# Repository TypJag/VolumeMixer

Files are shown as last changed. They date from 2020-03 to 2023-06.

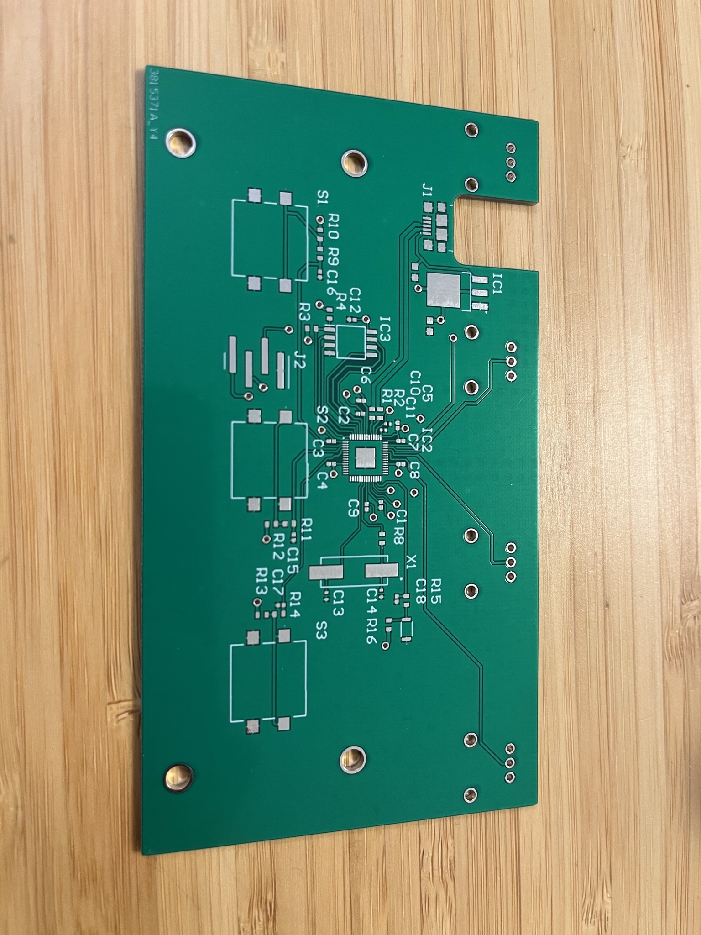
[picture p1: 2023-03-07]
Dokumentation/Bilder/IMG_0470.JPEG

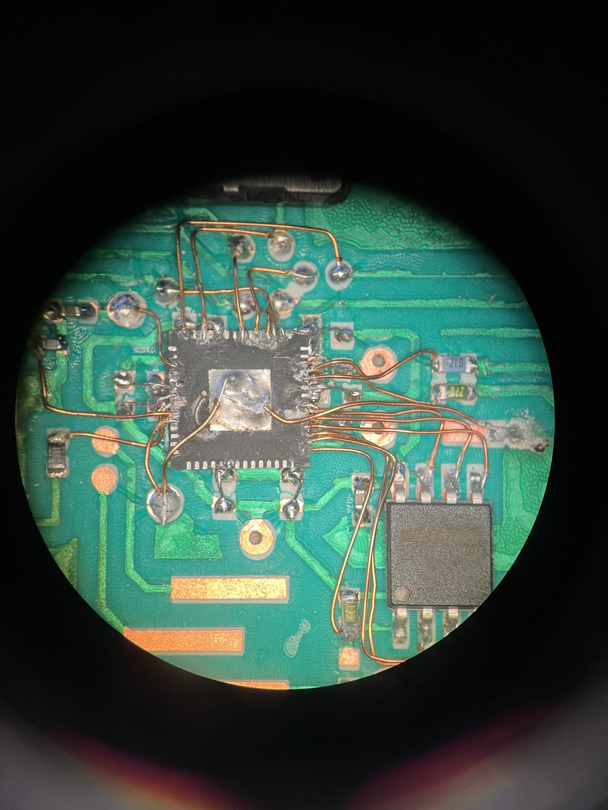
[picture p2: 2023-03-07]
Dokumentation/Bilder/IMG_0460.JPEG

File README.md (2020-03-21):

# VolumeMixer
A python script and arduino code for a hardware volume mixer for programs running on a Windows system

Link to a gallery of the project: https://www.sweclockers.com/galleri/15041-volymmixer

The hardware used is a simple arduino nano clone. 

Some modifications of the python script might be required for it to work with another arduino. In the findarduinoNano function there is a int called pid which is used to identifi COM-port the arduino is connected to. More intructions is in the comments in the script.

The shortcut needs to be uppdated with the correct path to the python script and the python install directory.

Some packages are needed to run the python script. More info in the script.

The arduino code requires bounce2.h. https://github.com/thomasfredericks/Bounce2

This project uses nircmd.exe by NirSoft https://www.nirsoft.net/utils/nircmd.html

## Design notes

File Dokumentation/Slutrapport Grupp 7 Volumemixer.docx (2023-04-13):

# Projekt VolumeMixer

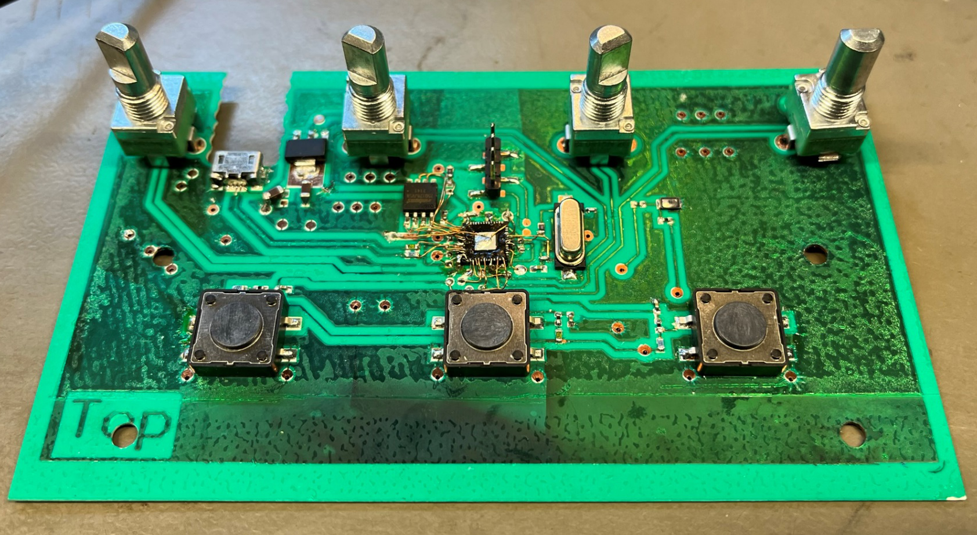
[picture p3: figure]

# Slutrapport för grupp 7

Vårtermin 2023

Axel Andersson Axean603

Linköpings universitet

# Sammanfattning

I detta projekt har ett kretskort för utvecklats. Kortets funktion är att agera ett fysiskt gränssnitt för att kontrollera individuella applikationers ljudvolym som körs på en vanlig dator. Kortet ger också möjlighet att styra uppspelningen av media på datorn genom att ha tre knappar som kontrollerar paus/play, nästa låt och föregående låt.

För att utföra dessa funktioner så används en Raspberry RP2040 mikrokontroller som kommunicerar användarens kommandon till en dator via USB. Närmare bestämt kommunicerar mikrokontrollern med ett Python skript som utför användarens kommandon.

För att kunna implementera RP2040 mikrokontrollern var ett ovanligare monteringssätt tvungen att användas för att arbeta runt de begränsningarna som finns i när mönsterkort görs i Linköpings Universitets mönsterkortslaboratorium. För att komma runt begränsningarna så ”dead bug” monterades mikrokontrollern, d.v.s. att kretsen lades på rygg och sedan drogs korta patchtrådar ut från kompentens paddar ut till paddar på mönsterkortet.

Efter kort felsökning av kortet efter montage startade mikrokontrollern och kortet fungerar som förväntat.

# Innehåll

# Förkortningar

Förkortning | Betydelse
Liu | Linköpings Universitet
MCU | Mikrokontroller
GPIO | Generel Purpose Input Output
I/O | Input Output
LDO | Low-dropout regulator
SRAM | Static Random Access Memory
ADC | Analog Digital Konverterare
SPI | Serial Peripheral Interface

# 1 Introduktion

En stor del av jobbet som elektronikingenjör är att konstruera kretsar. Dessa kretsar av olika slag måste därefter realiseras på ett eller annat sätt.

Det som har visat sig vara det dominerande alternativet att realisera kretsar idag är mönsterkort. En konstruktionsmetod som både har stora fördelar i produktions sammanhang samt tillåter den moderna elektronikingenjören konstruera mycket små kretsar av olika former och slag. Mönsterkort har också fördelen att man kan konstruera sina kretsar med mycket fin kontroll över geometrin av ledarna vilket kan användas till stor fördel då frekvenserna i signalerna stiger.

Som då blivande elektronikingenjörer är ett naturligt steg i utbildningen att vi ska bekanta oss med mönsterkortens konstruktion och produktion, vilket är målet och syftet med kursen ”Metoder och processer vid elektronikproduktion” (TNE087) som det här projektet är en del av.

Projektet har innefattat att konstruera en elektrisk konstruktion av valfri modell och sedan realisera den på ett mönsterkort.

Målet med det här projektet har mer specifikt varit att implementera Raspberry Pi Foundations mikrokontroller RP2040. Mikrokontrollerns mening är då att agera som fysiskt användargränssnitt för volymmixern som finns inbyggt i Windowsdatorer som ställer ljudvolymen för olika program som körs på datorn.

Kortet skulle också vara anpassat för att kunna tillverkas i Linköpings Universitets (Liu) mönsterkortslaboratorium. Mönsterkorten tillverkas där med hjälp av en etsande metod där en fotofilm används för att exponera valda delar utav en fotoresist.

Rekommenderade begränsningarna i mönsterkortslaboratoriumet är kortfattat:

- Två lager
- 160x160 mm
- Minsta ledarbredd 0,4 mm
- Minsta clearance ledare 0,5 mm
- Minsta borrdiameter 0,4 mm

# 2 Kortets kretsar och deras implementation

Nedan finns information gällande de kretsar som användes på kortet och hur de skall implementeras.

## Raspberry Pi Foundations RP2040

Kortfattat är RP2040 en lågkostnads, högpresterande mikrokontroller.

Nyckelfunktioner är som följande:

- Dubbla Cortex M0+ kärnor, klockade upp till 133 MHz
- 264 kB av integrerat SRAM
- 30 multifunktionella GPIO (General Purpose Input Output)
- Dedikerad hårdvara för vanliga kringutrustningar
- 4-kanalers ADC (Analog digital konverterare)
- USB 1.1 Host/Device

[1]

Se figur 1 nedan för en översikt av RP2040 interna uppbyggnad.

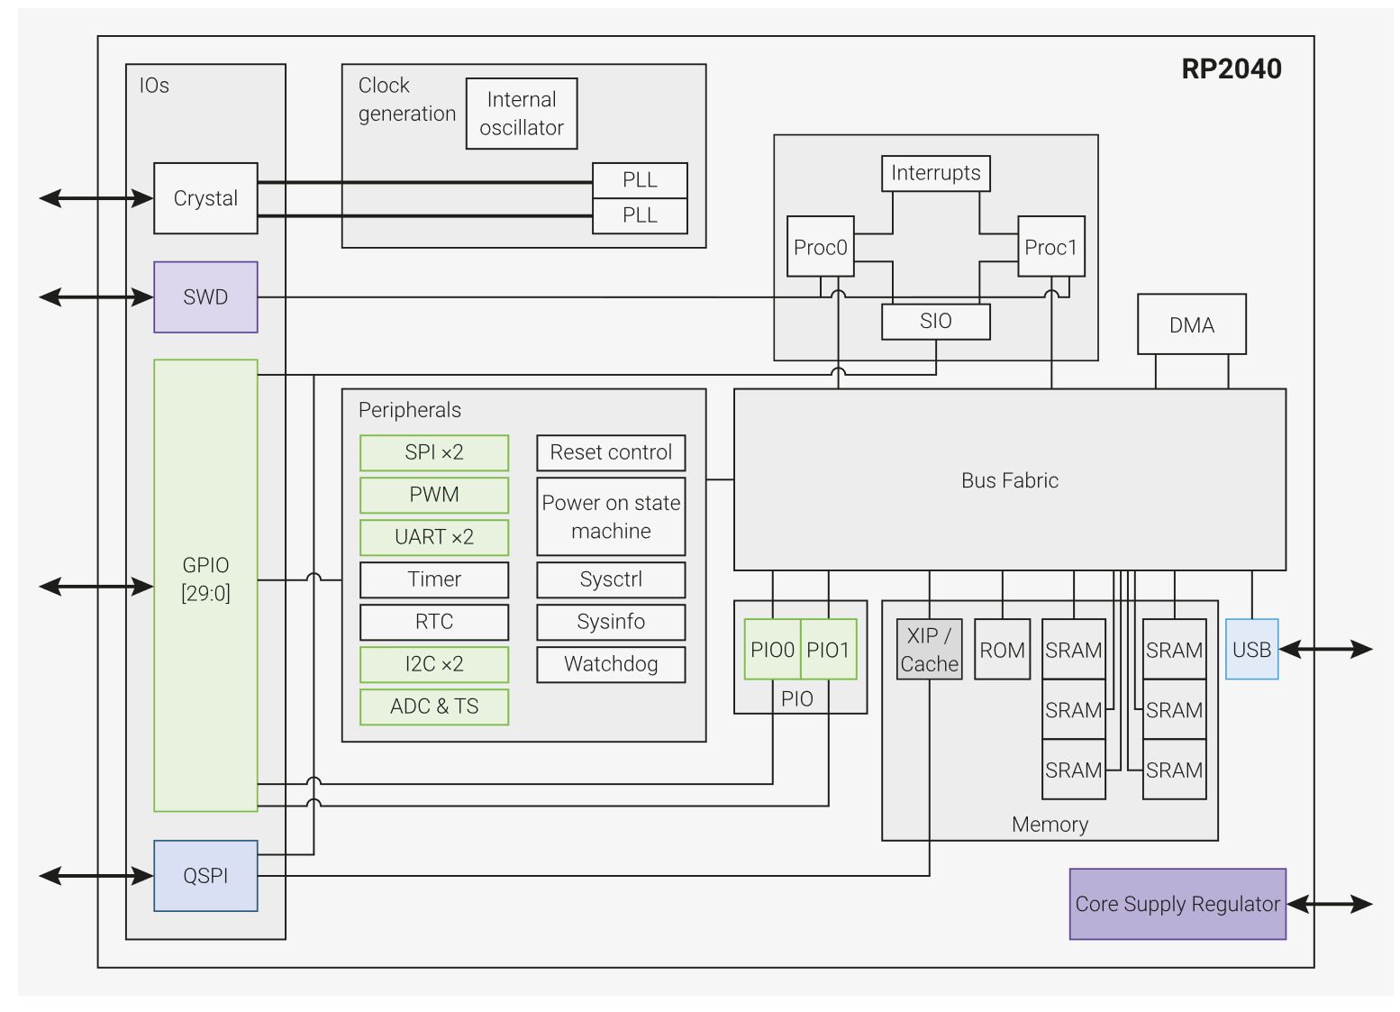
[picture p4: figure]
En bild som visar diagram, schematisk Automatiskt genererad beskrivning

Figur 1 Översikt över RP2040's interna uppbyggnad. Figuren är tagen från kretsens datablad [1].

För att framgångsrikt implementera RP2040 kretsen krävs följande tre saker [2]:

- Spänningsmatning
- SPI-minne
- Kristalloscillator

Mer ingående beskrivningar av vad som krävs kan läsas nedan.

### Spänningsmatning

RP2040 kräver två spänningar 3,3 V (för I/O) och 1,1 V (för kretsens digitala kärna) [2]. Praktiskt nog finns en inbyggd LDO (Low-dropout regulator) som kan användas för att generera 1V1 till kretsen.[2]

### Inkommande matning

Kortet kommer alltid vara inkopplad till en dator och kommer därför alltid att matas med 5 V. Den inkommande 5 V kan sedan användas för att generera 3,3 V som kan användas för att driva RP2040 kretsen.

För att generera 3,3 V i den här konstruktionen användes en LDO. Närmare bestämt användes Onsemi’s NCP1117ST33T3G dels för att den rekommenderas i Raspberry Pi foundation’s ”hardware design with RP2040” [2] och för att den råkade finns i Litheels lager. LDOn skall enligt dess datablad ha en kondensator på 1 0µF kopplat till inkommande spänning och en kopplad till utgående spänning [3].

### Avkopplingskondensatorer

Till RP2040 rekommenderas det att det finns avkopplingskondensatorer i närheten av paddarna för inkommande spänningsmatning till kretsen [2]. Generellt är rekommendationen 100 nF vid varje padd samt 1 µF i närheten av padden till LDOn som genererar 1,1 V [2]. 1,1 V rekommenderas också finns i närheten av utgången från LDOn. Dessa kondensatorer har två grundläggande funktioner, att filtrera ut brus som finns på spänningsmatningen och vara en källa till energi som RP2040 kretsen kan använda när den tillfälligt använder mycket energi till exempel vid omslag på en utgång [2].

### SPI-minne

För att kunna spara programkod som mikrokontrollern kan köra så krävs ett externt minne. I det här fallet användes ett W25Q128JVS vilket är ett quad SPI (Serial Peripheral Interface) flash minne på 128 Mbit. Detta minne valdes i och med att det användes i Raspberry Pi Foundations ”hardware design with RP2040” implementation [2].

### Kristalloscillator

Tekniskt sätt behövs inte en extern oscillator för RP2040 skall fungera utan den har en inbyggd oscillator men i och med att den inte är speciellt stabil rekommenderar Raspberry Pi Foundation att en extern klockkälla bör användas. I det här fallet användes en ABLS-12.000MHZ-B4-T vilket är en 12 MHz kristalloscillator. Den implementerades i enlighet med Raspberry Pi Foundations ”hardware design with RP2040” rekommendationer [2].

## Partikulära detaljer relaterat med det här kortets funktioner

### USB

RP2040 har möjlighet att kommunicera över USB i fullspeed(12Mbps) och lowspeed(1.5Mbps) [1] som antingen host eller device. För det här projektet så utnyttjades det genom att RP2040n konfigurerades att agera som device och kommunicera med ett Python skript på värddatorn med hjälp av en virtuell serieport som kommuniceras över USB. Ytterligare så programmeras kretsen enklast över USB så en fungerande USB implementation var ett krav.

För att USB skall fungera som förväntat så finns vissa krav kortet. Närmare bestämt bör ledarna för USB data paret dels vara terminerade med ett varsitt seriekopplat 27.4 Ω motstånd och att parets ledare skall ha en differentiell impedans på 90 Ω [2].

### I/O som används

Totalt kommer sju I/O pinnar att användas. De fyra pinnarna som är kopplad till de fyra kanalerna på den interna ADCn i RP2040n kommer att kopplas till varsin potentiometer och kommer att användas för att kontrollera volymen för fyra olika applikationer som kör på värddatorn. Tre I/O pinnar kommer vara kopplade till tre tryckknappar.

# 3 Projektets genomförande

## Konstruktion av schema

Schemat konstruerades i enlighet med de krav som detaljeras under rubriken 3 ”Detaljer kring kortets kretsar och deras implementation”. Majoriteten av schemasymbolerna och PCB footprintsen importerades med hjälp av Altium Library Loader för att spara tid. En del av symbolerna så som symbolen för RP2040 modifierades dock för att öka läsbarheten i schemat. Även en del av PCB footprinten modifierades för att korrigera fel från den troligen automatiserade processen som Altium Library Loader använder för att ska symbolerna och footprinten hade fått med. Komplett schema kan ses i bilaga 3.

## Konstruktion av layout

Två varianter konstruerades, en variant anpassad att tillverkas av ett vanligt produktionshus i det här fallet JLCpcb och en variant anpassad för att tillverkas i Lius mönsterkortslaboratorium. Storleken på kortet samt var potentiometrarna, monteringshål och tryckknapparna är placerades bestämdes utifrån den redan tillverkade mekaniken. Komplett layout kan ses i bilaga 2.

### Variant anpassad för JLCpcb

För JLCpcb konstruerades en variant på kortet som var anpassad för deras enklaste två lagers kort. Exakta begränsningar kan läsas på JLCpcbs hemsida [4].

### Variant anpassad för Lius mönsterkortslaboratorium

Att anpassa kortet för att kunna tillverkas på Lius mönsterkortslaboratorium var en större utmaning ty begränsningarna var större och marginalerna måste därför ökas för att lyckas producera ett fungerande mönsterkort.

Den största svårigheten med att anpassa den här konstruktionen att vara producerabar i Lius mönsterkortslaboratorium var hur footprinten för RP2040 mikrokontrolern skulle utformas. RP2040 kretsen är i en så kallad QFN-56 kapsling som är 7x7 mm stor med en pitch på 0.4 mm mellan benen. Att lyckas tillverka det footprintet framgångsrikt i Lius mönsterkortslaboratorium hade varit en stor utmaning. Istället togs beslutet att kretsen skulle monteras i ”dead bug” stil d.v.s. att kretsen läggs på rygg och små patch trådar dras från komponentens ben till paddar på kortet. På det sättet kan större geometrier göras på kortet och vilket gör att kortet är enklare att producera.

För att framgångsrikt kunna ”dead bug” montera kretsen gjordes även en del anpassningar på omkringliggande kretsar och komponenter. Den största anpassningen var hur avkopplingskondensatorerna placerades och monterades. Istället för att bara montera dem direkt på kortet ställdes de på högkant längs med kanten på mikrokontrollern och då kondensatorer i storleken 0402 användes var kondensatorerna lika långa som mikrokontrollern var tjock. Vilket gjorde inkopplingen av kondensatorerna väldigt enkel. Ytterligare modifierades vissa av footprinten för kondensatorerna för att kunna montera flera kondensatorer mot samma padd för att passa in med hur spänningsmatningspinnararna var placerade på mikrokontrollern.

## Test av kort efter tillverkning

### Omonterat kort

Följande steg skall tas vid verifikation av omonterat kort.

- Alla ledare skall testas med en ohmmeter för att se att ledaren är kontinuerlig som förväntad.
- Alla ledare skall testas med en ohmmeter mot lämpliga närliggande ledare för att se att det inte finns några oväntade kortslutningar
- En visuell inspektion skall genomföras för att verifiera att mönsterkortet ser välskapt ut och inga uppenbara fel kan ses.

### Monterat kort innan uppstart

Följande steg skall tas vid verifikation av monterat kort innan uppstart.

- Alla ledare skall testas med en ohmmeter för att se att ledaren är kontinuerlig som förväntad och att lödningarna har utförts som de ska.
- Alla ledare skall testas med en ohmmeter mot lämpliga närliggande ledare för att se att det inte finns några oväntade kortslutningar
- En visuell inspektion skall genomföras för att verifiera att kretskortet ser välskapt ut och inga uppenbara fel kan ses.

### Monterat kort efter uppstart

Följande steg skall tas vid verifikation av monterat kort innan uppstart.

- Följande spänningsmatningarna skall mätas: 5 V 3,3 V samt 1,1 V.
- Kristalloscillatorn skall mätas för att verifiera att klockan har startat och har förväntad frekvens
- Kortet skall kopplas in till dator och programmeras
- Kortets funktioner skall verifieras genom att köra det förväntade programmet som kommunicerar potentiometrarnas läge samt tryckknapparnas status till värddatorn.
- Kortet skall monteras i mekaniken för att se att det passar

## Felsökning av kortet

### Vid första start

Strömbegränsningen nådes. Kortslutning mellan 3,3 V och jord. Försökte med värmekamera identifiera var. Var dock svårt att se exakt var men värmekameran gav ett område. Kapade därefter ledare för att undersöka närmare. Hittade en lödbrygga vid en av avkopplingskondensatorerna.

### Vid andra start

Strömbegränsningen nådes. Kopplade förbi LDOn och matar med 3,3 V direkt. Kortet drar mer rimligt ström. Ca 7 mA. Inget händer och 1,1 V generas inte som den ska. Testade experimentera med hur run signalen görs. Inget resultat. Bekräftar därefter att alla signaler är inkopplade som förväntat. Inget resultat.

Gör därefter en gissning att mikrokontrollern har dött vid experiment. Byter ut mikrokontrollern. Monterar den med absolut minsta möjliga inkopplingar. Endast matningar, klocka samt run och testenable inkopplat.

### Verifikation av inkoppling efter montage

Mäter då resistansen mellan 3,3 V och GND 0.8 Ω. Kopplar lös GND kopplingen till kretsen och mäter mellan GND benet på kretsen och 3,3 V på kretsen. Fortfarande 0.8 Ω.

Mäter på en ny omonterad krets. Fortfarande 0.8 Ω. Mäter där efter mellan benen för spänningsmatningen för 3,3 V. De bör vara ihopkopplade internt. Konstaterar då att kretsen är monterad 90 grader fel. Vid montage vändes kretsen kring fel axel.

### Justerar monteringen av kretsen

Verifierar att kretsen var rätt vriden och att inget är kortslutet. Kortet startar som förväntat. 1,1 V genereras som förväntat och klockan går. Kretsen svarar också som förväntat när den kopplas till en dator. Programmering tar dock inte.

### Verifikation av inkoppling av SPI-minne

Konstaterar att SD3 och SD0 har bytt plats vid montering. Efter korrigering kan kortet programmeras och tryckknapparna samt potentiometrarna ger utslag som förväntat.

# 4 Resultat

## Monterade kort tillverkade av JLCpcb

Se figur 2 nedan för resultat

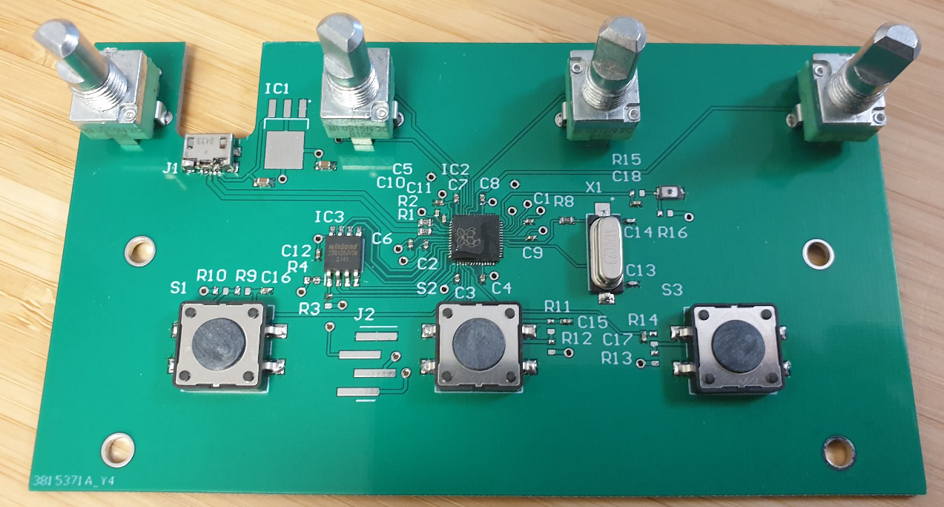
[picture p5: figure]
En bild som visar elektronik, krets Automatiskt genererad beskrivning

Figur 2 Monterat kretskort med mönsterkort tillverkat av JLCpcb

## Monterade kort tillverkade i Lius mönsterkortslaboratorium

Se figur 3 och 4 nedan för resultat

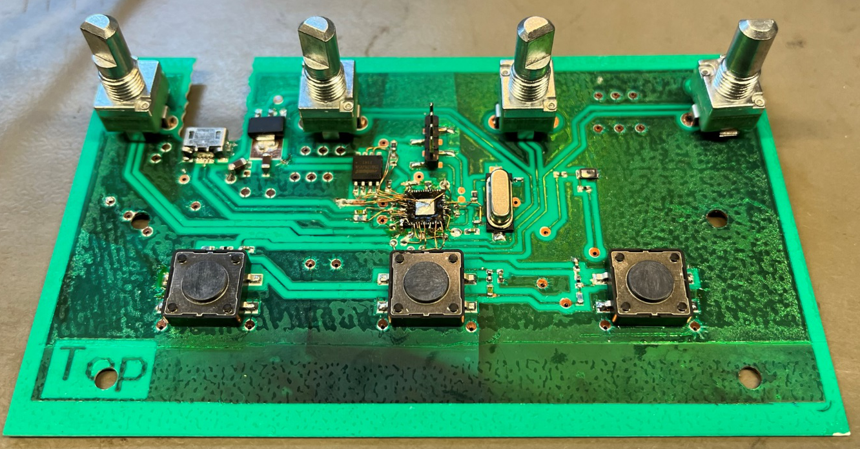
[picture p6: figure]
En bild som visar text, elektronik, krets Automatiskt genererad beskrivning

Figur 3 Monterat kretskort med mönsterkort tillverkat i Lius mönsterkortslaberatorium

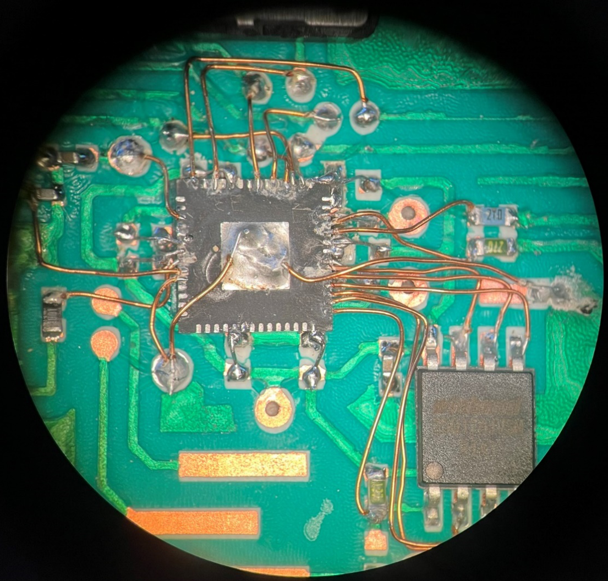
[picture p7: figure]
En bild som visar text Automatiskt genererad beskrivning

Figur 4 "Dead bug" monterad MCU

# 5 Diskussion och slutsatser

## Varför kortet inte riktigt blev som underlaget

Som kan ses på några av ledarna i figur 3 så finns en del förvrängningar i det slutgiltiga resultatet. En del av ledarna har blivit betydligt tunnare än förväntat.

Den största faktorn för varför de blev så pass förvrängda i visa områden är troligen att fotofilmen blev förvrängd när den skrevs ut. Det var stora problem med att få skrivaren att fungera när fotofilmen skulle göras. Hade både problem med att få den att skriva ut överhuvudtaget och när den väl skrev ut var allt förskjutet i y-led. Nu visade det sig att dessa förvrängningar inte var ett problem och kortet fungerade som förväntat.

## Potentiella förbättringar

Nedan är några idéer på förbättringar som kunde ha gjorts på konstruktionen samt vid montage.

- Ett tjockare laminat kunde ha använt för att få ett stabilare kort. Nu sviktar kortet något när knapparna trycks ned. Vid tillverkning fanns dock inget Rogers laminat i tjockare tjocklekar tillgängligt.
- Hållen för montering till chassit kunde ha inkluderats i underlaget och varit i korrekt storlek. Lades in manuellt i drill-filen, dock tyvärr som 3mm hål istället för 4mm som de borde ha varit.
- Olackade koppartrådar kunde ha använts med teflon slangar som isolation istället för lackade koppartrådar. Skulle potentiellt ha sparat en del tid vid montage. Har sätt det användas på projekt på internet och skulle vara intressant att testa och jämföra med nuvarande metod.

# 6 Slutsats

Det går att implementera en RP2040 mikrokontroller på ett mönsterkort tillverkat i Lius mönsterkortslabaratorium om konstruktionen anpassas till begränsningarna som finns och en del av det mer finkänsliga geometrierna görs i form av patcharbete i stället.

Kortet fungerade när det var korrekt monterat som förväntat och konstruktionen når de krav som var ställda.

# Referenser

1. Raspberry Pi Foundation. (den 20 mars 2023). RP2040 Datasheet. Hämtat från

https://datasheets.raspberrypi.com/rp2040/rp2040-datasheet.pdf

2. Raspberry Pi Foundation. (den 20 mars 2023). Hardware design with RP2040. Hämtat från

https://datasheets.raspberrypi.com/rp2040/hardware-design-with-rp2040.pdf

3. ON Semiconductor. (den 20 mars 2023). NPC1117 Datasheet. Hämtat från

https://www.mouser.se/datasheet/2/308/NCP1117_D-1595886.pdf

4. JLCpcb. (den 28 mars 2023). PCB Manufacturing & Assembly Capabilities.

https://jlcpcb.com/capabilities/pcb-capabilities

# Bilaga A Komponentlista

Tabell 1 Komponentlista

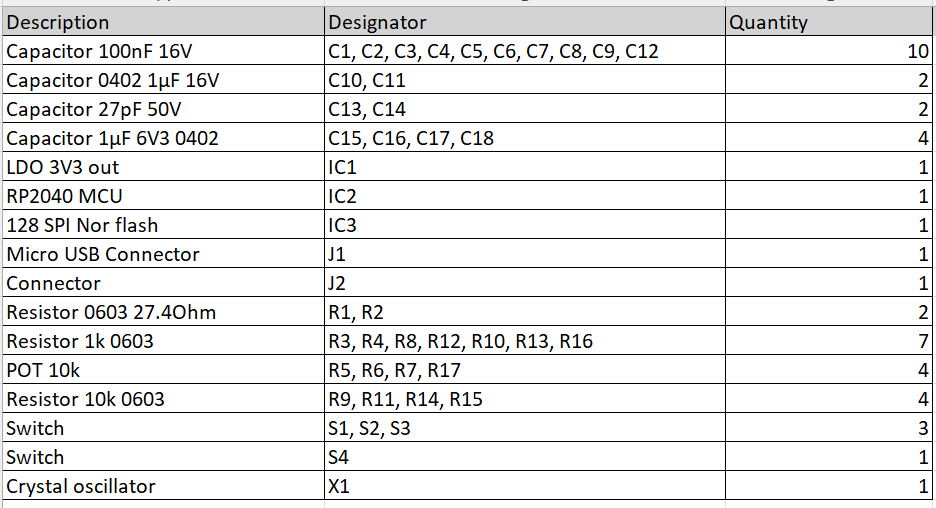
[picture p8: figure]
En bild som visar bord Automatiskt genererad beskrivning

# Bilaga B Layout filer

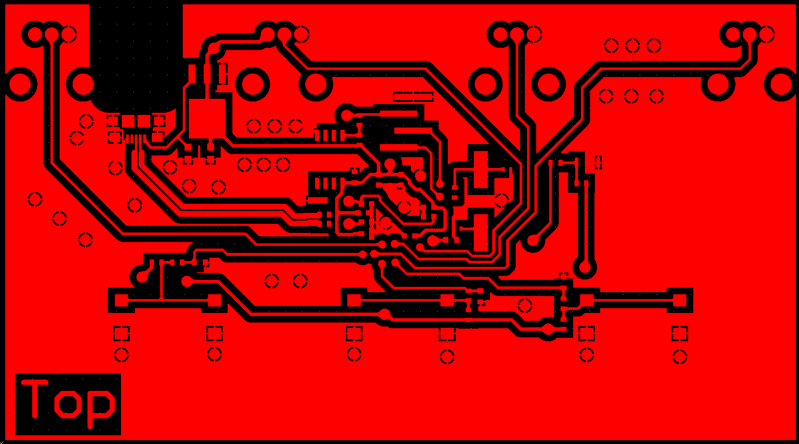
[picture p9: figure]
En bild som visar diagram Automatiskt genererad beskrivning

Figur 5 Ledarmönster topp

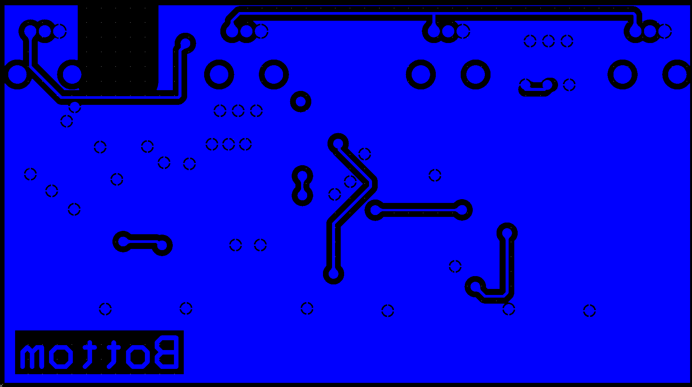
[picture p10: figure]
En bild som visar text Automatiskt genererad beskrivning

Figur 6 Ledarmönster botten

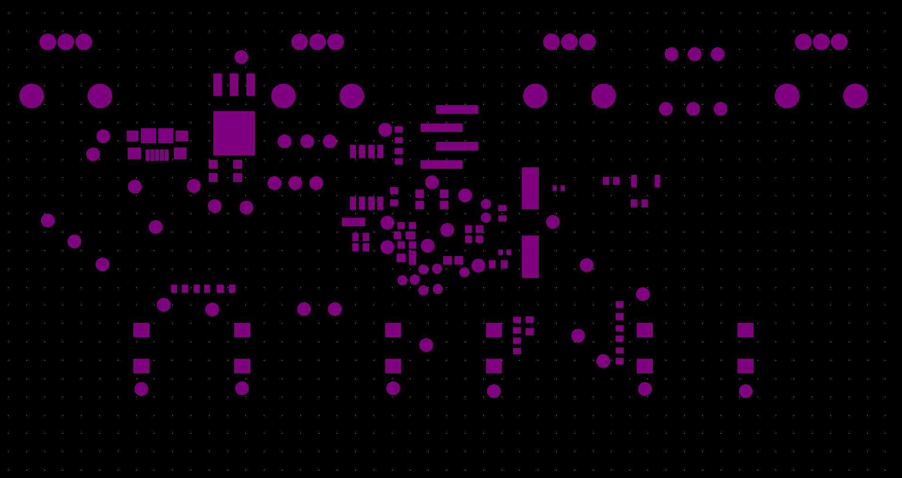
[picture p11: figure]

Figur 7 Lödmasksöppningar topp

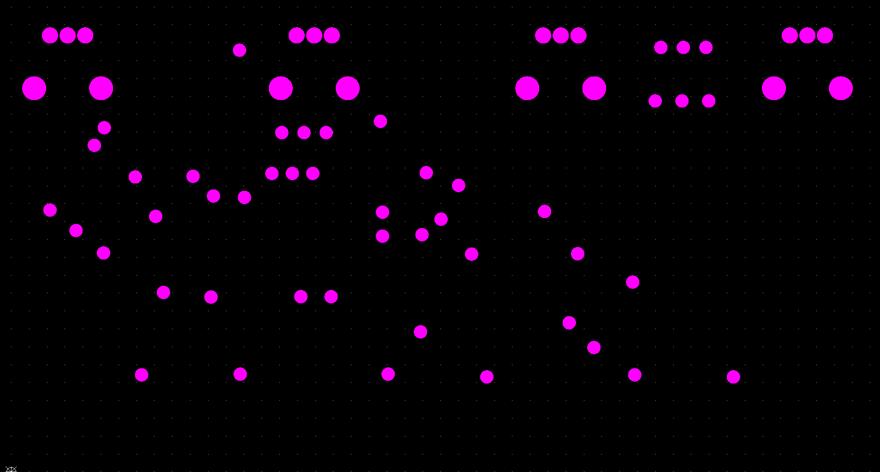
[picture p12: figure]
En bild som visar inomhus, ljus Automatiskt genererad beskrivning

Figur 8 Lödmasksöppningar botten

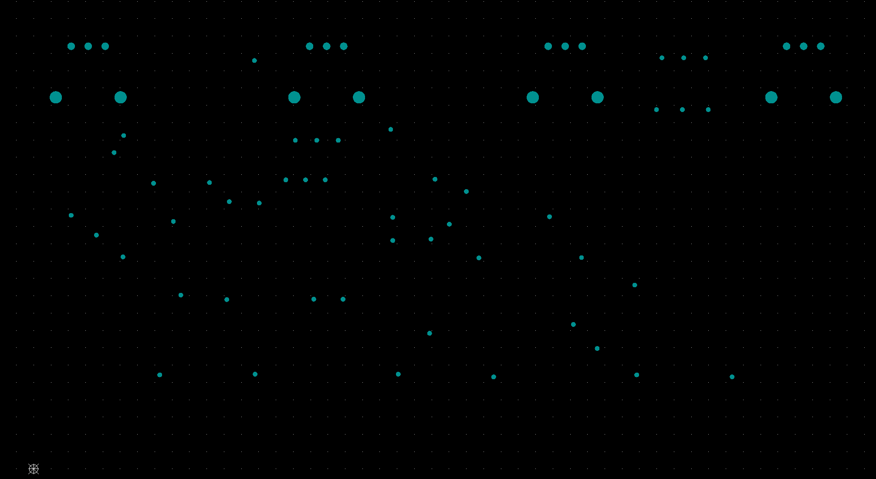
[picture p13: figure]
En bild som visar tangentbord Automatiskt genererad beskrivning

Figur 9 Drill fil

# Bilaga C Schema

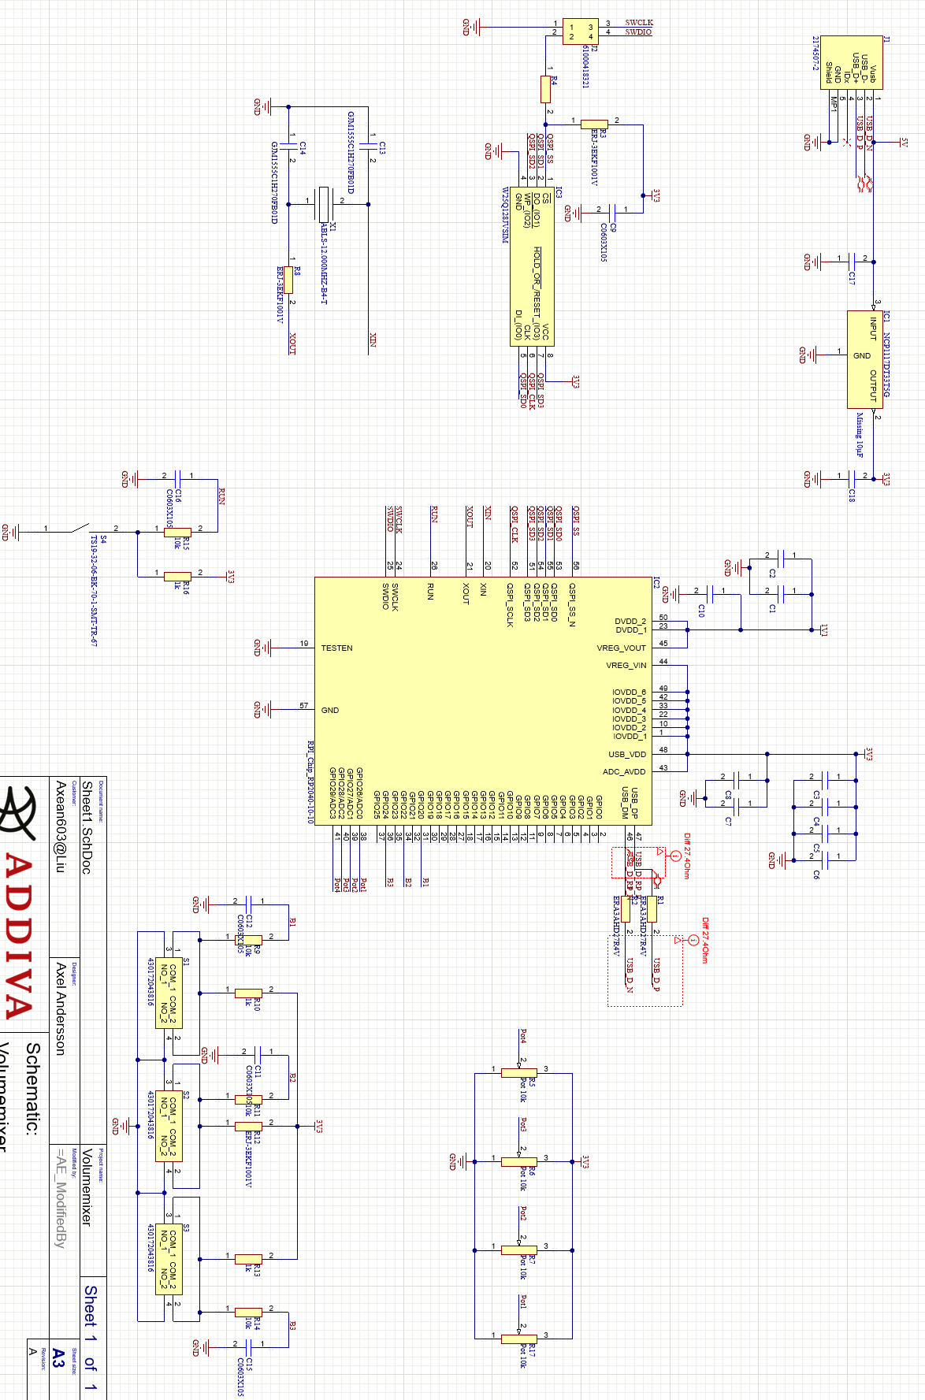
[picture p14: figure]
En bild som visar diagram, schematisk Automatiskt genererad beskrivning

# Bilaga D Tidsplan och tidsrapportering

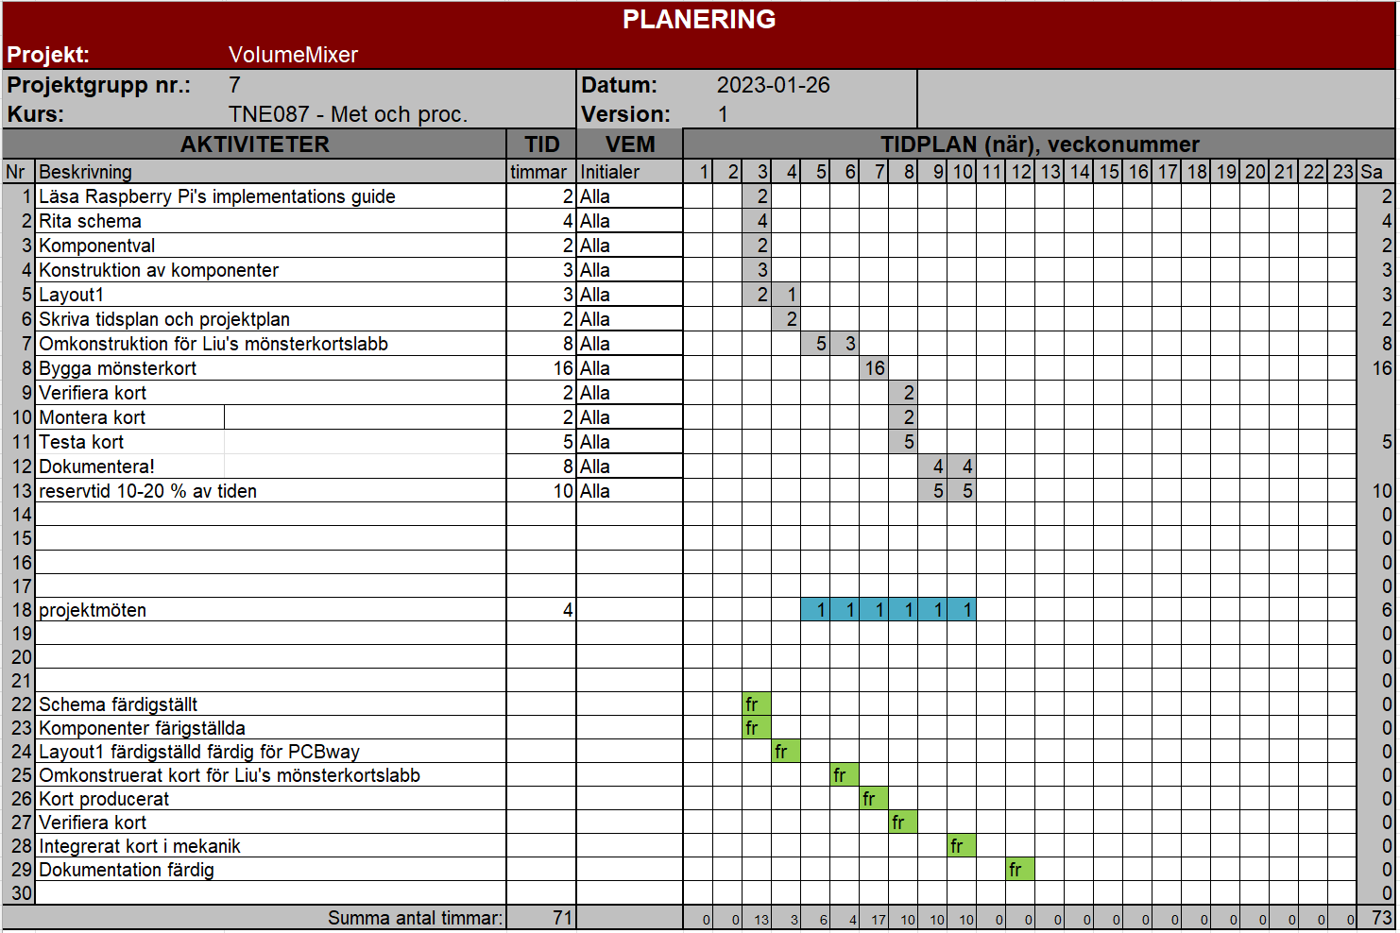
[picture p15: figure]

Figur 10 Tidsplan

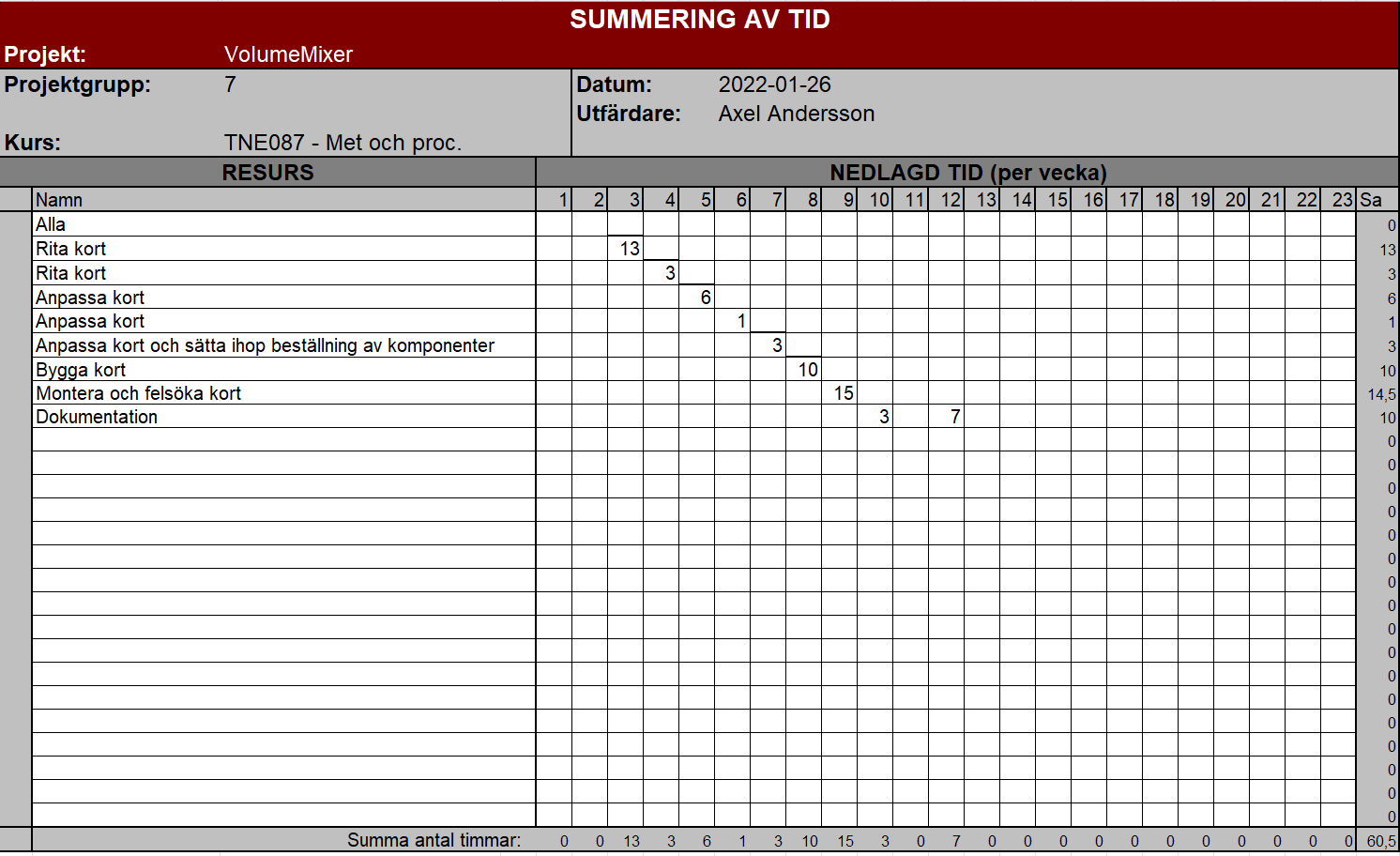
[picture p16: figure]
En bild som visar bord Automatiskt genererad beskrivning

Figur 11 Tidsrapportering

# Bilaga E Status

Vem har gjort vad:
Axel Andersson har gjort allt.

2 Axel Andersson

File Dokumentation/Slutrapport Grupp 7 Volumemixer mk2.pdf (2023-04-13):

# Projekt VolumeMixer

## Slutrapport för grupp 7

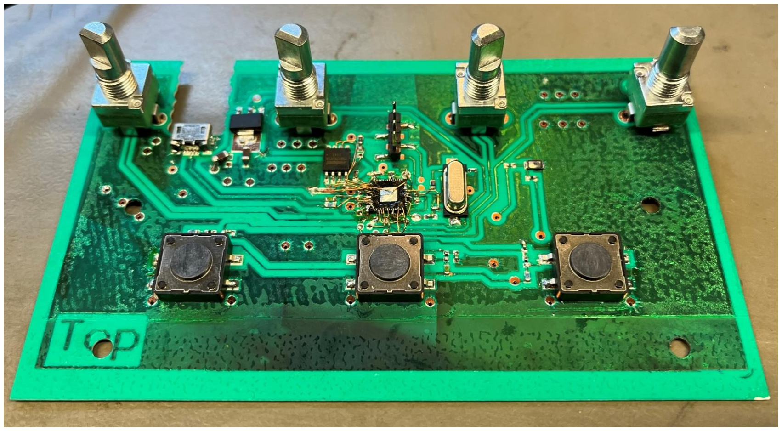
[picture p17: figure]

## Vårtermin 2023

## Axel Andersson Axean603

Linköpings universitet

# Sammanfattning

I detta projekt har ett kretskort för utvecklats. Kortets funktion är att agera ett fysiskt gränssnitt för att kontrollera individuella applikationers ljudvolym som körs på en vanlig dator. Kortet ger också möjlighet att styra uppspelningen av media på datorn genom att ha tre knappar som kontrollerar paus/play, nästa låt och föregående låt.

För att utföra dessa funktioner så används en Raspberry RP2040 mikrokontroller som kommunicerar användarens kommandon till en dator via USB. Närmare bestämt kommunicerar mikrokontrollern med ett Python skript som utför användarens kommandon.

För att kunna implementera RP2040 mikrokontrollern var ett ovanligare monteringssätt tvungen att användas för att arbeta runt de begränsningarna som finns i när mönsterkort görs i Linköpings Universitets mönsterkortslaboratorium. För att komma runt begränsningarna
så ”dead bug” monterades mikrokontrollern, d.v.s. att kretsen lades på rygg och sedan drogs korta patchtrådar ut från kompentens paddar ut till paddar på mönsterkortet.

Efter kort felsökning av kortet efter montage startade mikrokontrollern och kortet fungerar som förväntat.

# Innehåll

Axel Andersson

# Förkortningar

Förkortning | Betydelse
Liu | Linköpings Universitet
MCU | Mikrokontroller
GPIO | Generel Purpose Input Output
I/O | Input Output
LDO | Low-dropout regulator
SRAM | Static Random Access Memory
ADC | Analog Digital Konverterare
SPI | Serial Peripheral Interface

# 1 Introduktion

En stor del av jobbet som elektronikingenjör är att konstruera kretsar. Dessa kretsar av olika slag måste därefter realiseras på ett eller annat sätt.

Det som har visat sig vara det dominerande alternativet att realisera kretsar idag är mönsterkort. En konstruktionsmetod som både har stora fördelar i produktions sammanhang samt tillåter den moderna elektronikingenjören konstruera mycket små kretsar av olika former och slag. Mönsterkort har också fördelen att man kan konstruera sina kretsar med mycket fin kontroll över geometrin av ledarna vilket kan användas till stor fördel då frekvenserna i signalerna stiger.

Som då blivande elektronikingenjörer är ett naturligt steg i utbildningen att vi ska bekanta oss med mönsterkortens konstruktion och produktion, vilket är målet och syftet med kursen ”Metoder och processer vid elektronikproduktion” (TNE087) som det här projektet är en del av.

Projektet har innefattat att konstruera en elektrisk konstruktion av valfri modell och sedan realisera den på ett mönsterkort.

Målet med det här projektet har mer specifikt varit att implementera Raspberry Pi Foundations mikrokontroller RP2040. Mikrokontrollerns mening är då att agera som fysiskt användargränssnitt för volymmixern som finns inbyggt i Windowsdatorer som ställer ljudvolymen för olika program som körs på datorn.

Kortet skulle också vara anpassat för att kunna tillverkas i Linköpings Universitets (Liu) mönsterkortslaboratorium. Mönsterkorten tillverkas där med hjälp av en etsande metod där en fotofilm används för att exponera valda delar utav en fotoresist.

Rekommenderade begränsningarna i mönsterkortslaboratoriumet är kortfattat:
- Två lager
- 160x160 mm
- Minsta ledarbredd 0,4 mm
- Minsta clearance ledare 0,5 mm
- Minsta borrdiameter 0,4 mm

# 2 Kortets kretsar och deras implementation

Nedan finns information gällande de kretsar som användes på kortet och hur de skall implementeras.

### 2.1 Raspberry Pi Foundations RP2040

Kortfattat är RP2040 en lågkostnads, högpresterande mikrokontroller.

Nyckelfunktioner är som följande:
- Dubbla Cortex M0+ kärnor, klockade upp till 133 MHz
- 264 kB av integrerat SRAM
- 30 multifunktionella GPIO (General Purpose Input Output)
- Dedikerad hårdvara för vanliga kringutrustningar
- 4-kanalers ADC (Analog digital konverterare)
- USB 1.1 Host/Device
[1]

Se figur 1 nedan för en översikt av RP2040 interna uppbyggnad.


Figur 1 Översikt över RP2040's interna uppbyggnad. Figuren är tagen från kretsens datablad [1].

För att framgångsrikt implementera RP2040 kretsen krävs följande tre saker [2]:
- Spänningsmatning
- SPI-minne
- Kristalloscillator
Mer ingående beskrivningar av vad som krävs kan läsas nedan.

### 2.1.1 Spänningsmatning

RP2040 kräver två spänningar 3,3 V (för I/O) och 1,1 V (för kretsens digitala kärna) [2]. Praktiskt nog finns en inbyggd LDO (Low-dropout regulator) som kan användas för att generera 1V1 till kretsen.[2]

### 2.1.2 Inkommande matning

Kortet kommer alltid vara inkopplad till en dator och kommer därför alltid att matas med 5 V. Den inkommande 5 V kan sedan användas för att generera 3,3 V som kan användas för att driva RP2040 kretsen.

För att generera 3,3 V i den här konstruktionen användes en LDO. Närmare bestämt användes Onsemi’s NCP1117ST33T3G dels för att den rekommenderas i Raspberry Pi foundation’s ”hardware design with RP2040” [2] och för att den råkade finns i Litheels lager. LDOn skall enligt dess datablad ha en kondensator på 1 0µF kopplat till inkommande spänning och en kopplad till utgående spänning [3].

### 2.1.3 Avkopplingskondensatorer

Till RP2040 rekommenderas det att det finns avkopplingskondensatorer i närheten av paddarna för inkommande spänningsmatning till kretsen [2]. Generellt är rekommendationen 100 nF vid varje padd samt 1 µF i närheten av padden till LDOn som genererar 1,1 V [2]. 1,1 V rekommenderas också finns i närheten av utgången från LDOn. Dessa kondensatorer har två grundläggande funktioner, att filtrera ut brus som finns på spänningsmatningen och vara en källa till energi som RP2040 kretsen kan använda när den tillfälligt använder mycket energi till exempel vid omslag på en utgång [2].

### 2.1.4 SPI-minne

För att kunna spara programkod som mikrokontrollern kan köra så krävs ett externt minne. I det här fallet användes ett W25Q128JVS vilket är ett quad SPI (Serial Peripheral Interface) flash minne på 128 Mbit. Detta minne valdes i och med att det användes i Raspberry Pi Foundations ”hardware design with RP2040” implementation [2].

### 2.1.5 Kristalloscillator

Tekniskt sätt behövs inte en extern oscillator för RP2040 skall fungera utan den har en inbyggd oscillator men i och med att den inte är speciellt stabil rekommenderar Raspberry Pi Foundation att en extern klockkälla bör användas. I det här fallet användes en ABLS-12.000MHZ-B4-T vilket är en 12 MHz kristalloscillator. Den implementerades i enlighet med Raspberry Pi Foundations ”hardware design with RP2040” rekommendationer [2].

### 2.2 Partikulära detaljer relaterat med det här kortets funktioner

### 2.2.1 USB

RP2040 har möjlighet att kommunicera över USB i fullspeed(12Mbps) och lowspeed(1.5Mbps) [1] som antingen host eller device. För det här projektet så utnyttjades det genom att RP2040n konfigurerades att agera som device och kommunicera med ett Python skript på värddatorn med hjälp av en virtuell serieport som kommuniceras över USB. Ytterligare så programmeras kretsen enklast över USB så en fungerande USB implementation var ett krav.

För att USB skall fungera som förväntat så finns vissa krav kortet. Närmare bestämt bör ledarna för USB data paret dels vara terminerade med ett varsitt seriekopplat 27.4 Ω motstånd och att parets ledare skall ha en differentiell impedans på 90 Ω [2].

### 2.2.2 I/O som används

Totalt kommer sju I/O pinnar att användas. De fyra pinnarna som är kopplad till de fyra kanalerna på den interna ADCn i RP2040n kommer att kopplas till varsin potentiometer och kommer att användas för att kontrollera volymen för fyra olika applikationer som kör på värddatorn. Tre I/O pinnar kommer vara kopplade till tre tryckknappar.

# 3 Projektets genomförande

### 3.1 Konstruktion av schema

Schemat konstruerades i enlighet med de krav som detaljeras under rubriken 3 ”Detaljer kring kortets kretsar och deras implementation”. Majoriteten av schemasymbolerna och PCB footprintsen importerades med hjälp av Altium Library Loader för att spara tid. En del av symbolerna så som symbolen för RP2040 modifierades dock för att öka läsbarheten i schemat. Även en del av PCB footprinten modifierades för att korrigera fel från den troligen automatiserade processen som Altium Library Loader använder för att ska symbolerna och footprinten hade fått med. Komplett schema kan ses i bilaga 3.

### 3.2 Konstruktion av layout

Två varianter konstruerades, en variant anpassad att tillverkas av ett vanligt produktionshus i det här fallet JLCpcb och en variant anpassad för att tillverkas i Lius mönsterkortslaboratorium. Storleken på kortet samt var potentiometrarna, monteringshål och tryckknapparna är placerades bestämdes utifrån den redan tillverkade mekaniken. Komplett layout kan ses i bilaga 2.

### 3.2.1 Variant anpassad för JLCpcb

För JLCpcb konstruerades en variant på kortet som var anpassad för deras enklaste två lagers kort. Exakta begränsningar kan läsas på JLCpcbs hemsida [4].

### 3.2.2 Variant anpassad för Lius mönsterkortslaboratorium

Att anpassa kortet för att kunna tillverkas på Lius mönsterkortslaboratorium var en större utmaning ty begränsningarna var större och marginalerna måste därför ökas för att lyckas producera ett fungerande mönsterkort.

Den största svårigheten med att anpassa den här konstruktionen att vara producerabar i Lius mönsterkortslaboratorium var hur footprinten för RP2040 mikrokontrolern skulle utformas. RP2040 kretsen är i en så kallad QFN-56 kapsling som är 7x7 mm stor med en pitch på 0.4 mm mellan benen. Att lyckas tillverka det footprintet framgångsrikt i Lius mönsterkortslaboratorium hade varit en stor utmaning. Istället togs beslutet att kretsen skulle monteras i ”dead bug” stil d.v.s. att kretsen läggs på rygg och små patch trådar dras från komponentens ben till paddar på kortet. På det sättet kan större geometrier göras på kortet och vilket gör att kortet är enklare att producera.

För att framgångsrikt kunna ”dead bug” montera kretsen gjordes även en del anpassningar på omkringliggande kretsar och komponenter. Den största anpassningen var hur avkopplingskondensatorerna placerades och monterades. Istället för att bara montera dem direkt på kortet ställdes de på högkant längs med kanten på mikrokontrollern och då kondensatorer i storleken 0402 användes var kondensatorerna lika långa som mikrokontrollern var tjock. Vilket gjorde inkopplingen av kondensatorerna väldigt enkel. Ytterligare modifierades vissa av footprinten för kondensatorerna för att kunna montera flera kondensatorer mot samma padd för att passa in med hur spänningsmatningspinnararna var placerade på mikrokontrollern.

### 3.3 Test av kort efter tillverkning

### 3.3.1 Omonterat kort

Följande steg skall tas vid verifikation av omonterat kort.

- Alla ledare skall testas med en ohmmeter för att se att ledaren är kontinuerlig som förväntad.
- Alla ledare skall testas med en ohmmeter mot lämpliga närliggande ledare för att se att det inte finns några oväntade kortslutningar
- En visuell inspektion skall genomföras för att verifiera att mönsterkortet ser välskapt ut och inga uppenbara fel kan ses.

### 3.3.2 Monterat kort innan uppstart

Följande steg skall tas vid verifikation av monterat kort innan uppstart.
- Alla ledare skall testas med en ohmmeter för att se att ledaren är kontinuerlig som förväntad och att lödningarna har utförts som de ska.
- Alla ledare skall testas med en ohmmeter mot lämpliga närliggande ledare för att se att det inte finns några oväntade kortslutningar
- En visuell inspektion skall genomföras för att verifiera att kretskortet ser välskapt ut och inga uppenbara fel kan ses.

### 3.3.3 Monterat kort efter uppstart

Följande steg skall tas vid verifikation av monterat kort innan uppstart.
- Följande spänningsmatningarna skall mätas: 5 V 3,3 V samt 1,1 V.
- Kristalloscillatorn skall mätas för att verifiera att klockan har startat och har förväntad frekvens
- Kortet skall kopplas in till dator och programmeras
- Kortets funktioner skall verifieras genom att köra det förväntade programmet som kommunicerar potentiometrarnas läge samt tryckknapparnas status till värddatorn.
- Kortet skall monteras i mekaniken för att se att det passar

### 3.4 Felsökning av kortet

### 3.4.1 Vid första start

Strömbegränsningen nådes. Kortslutning mellan 3,3 V och jord. Försökte med värmekamera identifiera var. Var dock svårt att se exakt var men värmekameran gav ett område. Kapade därefter ledare för att undersöka närmare. Hittade en lödbrygga vid en av avkopplingskondensatorerna.

### 3.4.2 Vid andra start

Strömbegränsningen nådes. Kopplade förbi LDOn och matar med 3,3 V direkt. Kortet drar mer rimligt ström. Ca 7 mA. Inget händer och 1,1 V generas inte som den ska. Testade experimentera med hur run signalen görs. Inget resultat. Bekräftar därefter att alla signaler är inkopplade som förväntat. Inget resultat.

Gör därefter en gissning att mikrokontrollern har dött vid experiment. Byter ut mikrokontrollern. Monterar den med absolut minsta möjliga inkopplingar. Endast matningar, klocka samt run och testenable inkopplat.

### 3.4.3 Verifikation av inkoppling efter montage

Mäter då resistansen mellan 3,3 V och GND 0.8 Ω. Kopplar lös GND kopplingen till kretsen och mäter mellan GND benet på kretsen och 3,3 V på kretsen. Fortfarande 0.8 Ω.

Mäter på en ny omonterad krets. Fortfarande 0.8 Ω. Mäter där efter mellan benen för spänningsmatningen för 3,3 V. De bör vara ihopkopplade internt. Konstaterar då att kretsen är monterad 90 grader fel. Vid montage vändes kretsen kring fel axel.

### 3.4.4 Justerar monteringen av kretsen

Verifierar att kretsen var rätt vriden och att inget är kortslutet. Kortet startar som förväntat. 1,1 V genereras som förväntat och klockan går. Kretsen svarar också som förväntat när den kopplas till en dator. Programmering tar dock inte.

### 3.4.5 Verifikation av inkoppling av SPI-minne

Konstaterar att SD3 och SD0 har bytt plats vid montering. Efter korrigering kan kortet programmeras och tryckknapparna samt potentiometrarna ger utslag som förväntat.

# 4 Resultat

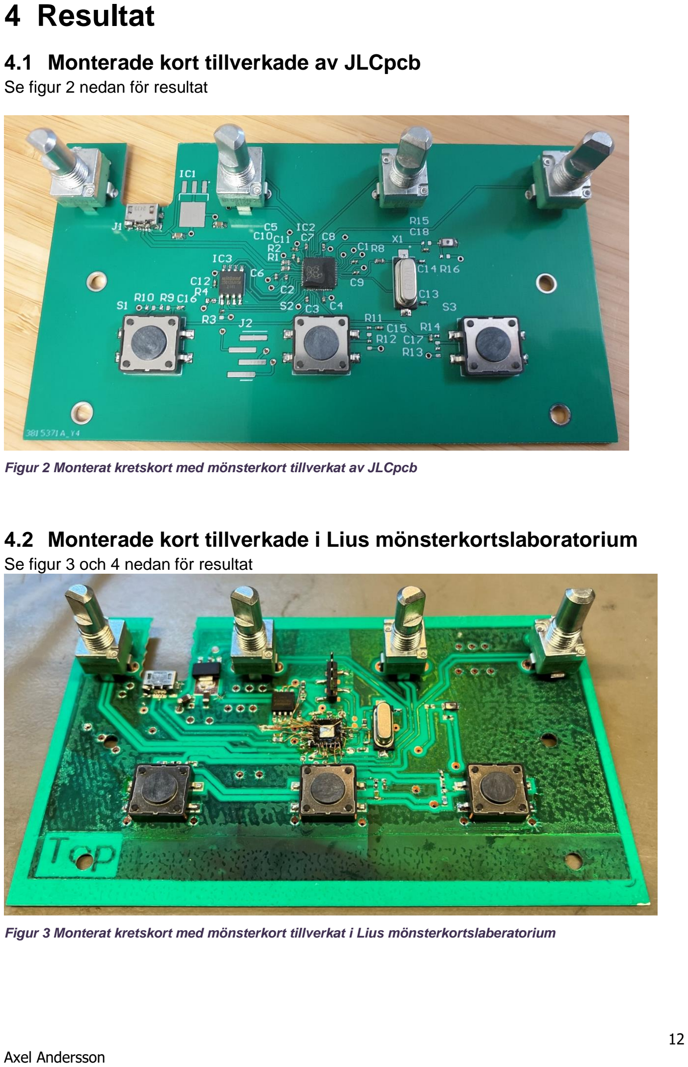
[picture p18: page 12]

### 4.1 Monterade kort tillverkade av JLCpcb

Se figur 2 nedan för resultat

Figur 2 Monterat kretskort med mönsterkort tillverkat av JLCpcb

### 4.2 Monterade kort tillverkade i Lius mönsterkortslaboratorium

Se figur 3 och 4 nedan för resultat

Figur 3 Monterat kretskort med mönsterkort tillverkat i Lius mönsterkortslaberatorium

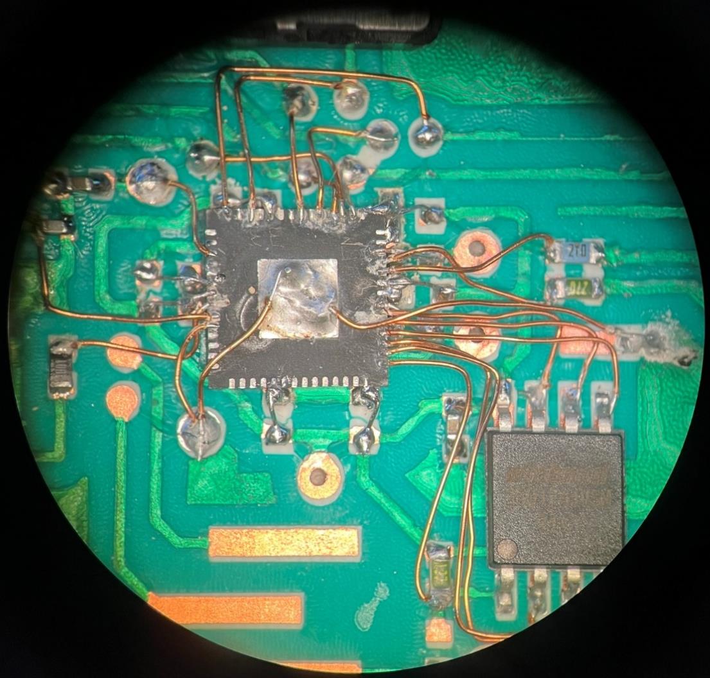
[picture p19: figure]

Figur 4 "Dead bug" monterad MCU

# 5 Diskussion och slutsatser

### 5.1 Varför kortet inte riktigt blev som underlaget

Som kan ses på några av ledarna i figur 3 så finns en del förvrängningar i det slutgiltiga resultatet. En del av ledarna har blivit betydligt tunnare än förväntat.

Den största faktorn för varför de blev så pass förvrängda i visa områden är troligen att fotofilmen blev förvrängd när den skrevs ut. Det var stora problem med att få skrivaren att fungera när fotofilmen skulle göras. Hade både problem med att få den att skriva ut överhuvudtaget och när den väl skrev ut var allt förskjutet i y-led. Nu visade det sig att dessa förvrängningar inte var ett problem och kortet fungerade som förväntat.

### 5.2 Potentiella förbättringar

Nedan är några idéer på förbättringar som kunde ha gjorts på konstruktionen samt vid montage.
- Ett tjockare laminat kunde ha använt för att få ett stabilare kort. Nu sviktar kortet något när knapparna trycks ned. Vid tillverkning fanns dock inget Rogers laminat i tjockare tjocklekar tillgängligt.
- Hållen för montering till chassit kunde ha inkluderats i underlaget och varit i korrekt storlek. Lades in manuellt i drill-filen, dock tyvärr som 3mm hål istället för 4mm som de borde ha varit.
- Olackade koppartrådar kunde ha använts med teflon slangar som isolation istället för lackade koppartrådar. Skulle potentiellt ha sparat en del tid vid montage. Har sätt det användas på projekt på internet och skulle vara intressant att testa och jämföra med nuvarande metod.

# 6 Slutsats

Det går att implementera en RP2040 mikrokontroller på ett mönsterkort tillverkat i Lius mönsterkortslabaratorium om konstruktionen anpassas till begränsningarna som finns och en del av det mer finkänsliga geometrierna görs i form av patcharbete i stället.

Kortet fungerade när det var korrekt monterat som förväntat och konstruktionen når de krav som var ställda.

# Referenser

1. Raspberry Pi Foundation. (den 20 mars 2023). RP2040 Datasheet. Hämtat från https://datasheets.raspberrypi.com/rp2040/rp2040-datasheet.pdf
2. Raspberry Pi Foundation. (den 20 mars 2023). Hardware design with RP2040. Hämtat från
https://datasheets.raspberrypi.com/rp2040/hardware-design-with-rp2040.pdf
3. ON Semiconductor. (den 20 mars 2023). NPC1117 Datasheet. Hämtat från https://www.mouser.se/datasheet/2/308/NCP1117_D-1595886.pdf
4. JLCpcb. (den 28 mars 2023). PCB Manufacturing & Assembly Capabilities. https://jlcpcb.com/capabilities/pcb-capabilities

# Bilaga A Komponentlista

Tabell 1 Komponentlista


# Bilaga B Layout filer

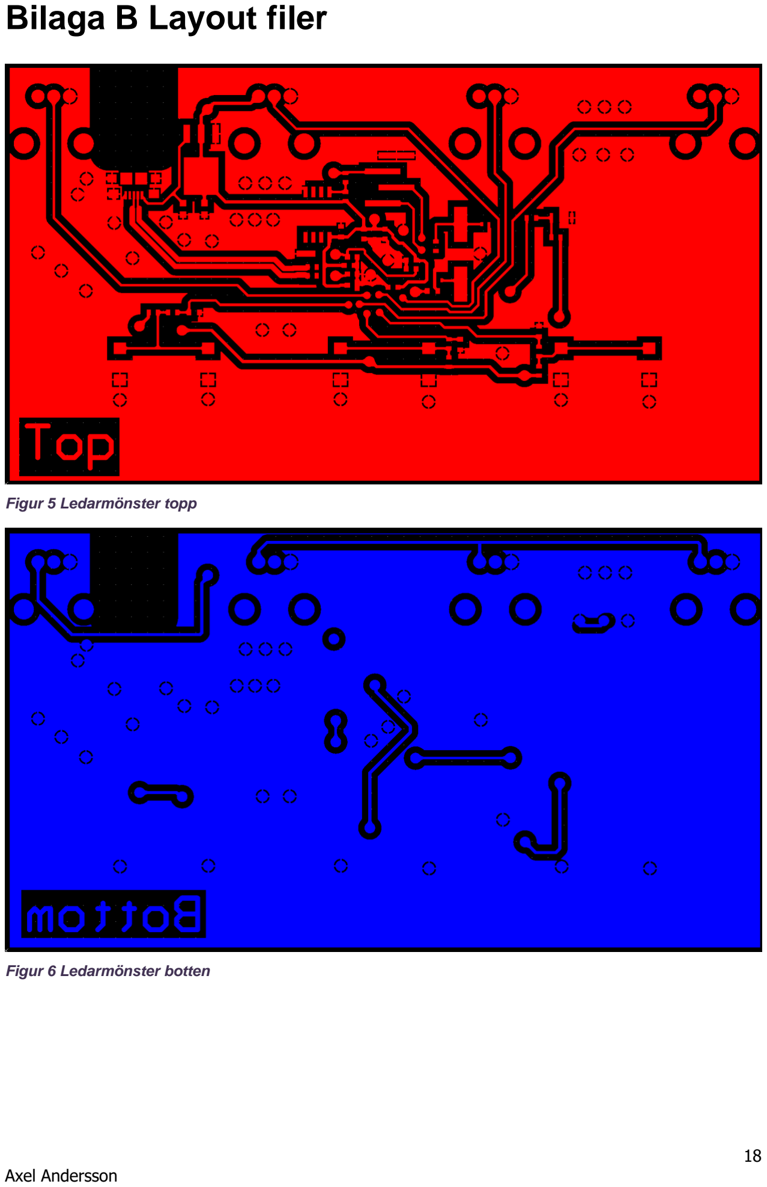
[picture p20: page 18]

Figur 5 Ledarmönster topp

Figur 6 Ledarmönster botten

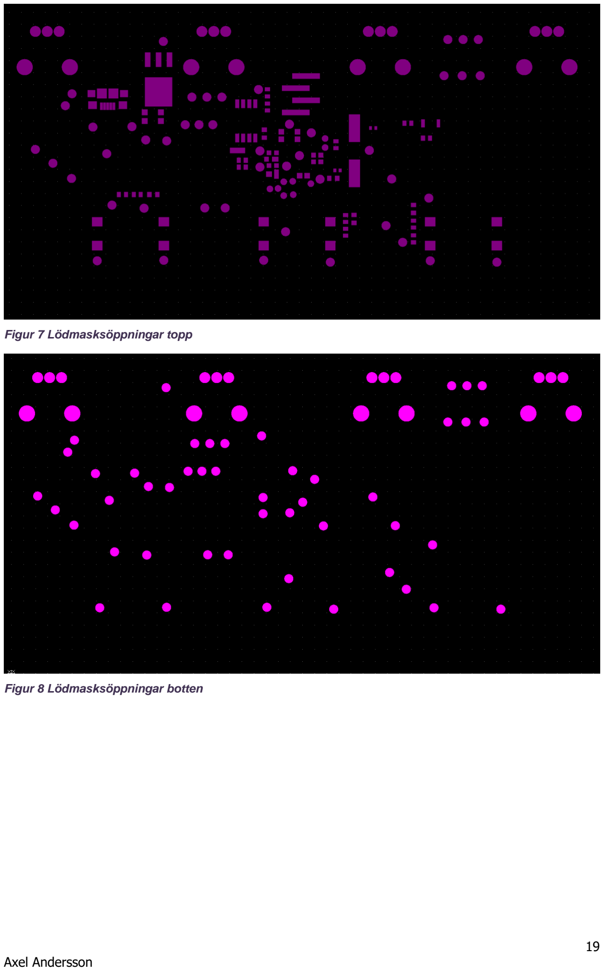
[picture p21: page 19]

Figur 7 Lödmasksöppningar topp

Figur 8 Lödmasksöppningar botten

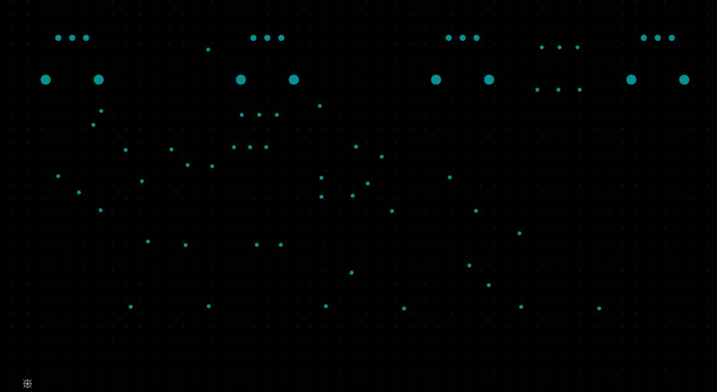
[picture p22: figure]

Figur 9 Drill fil

# Bilaga C Schema

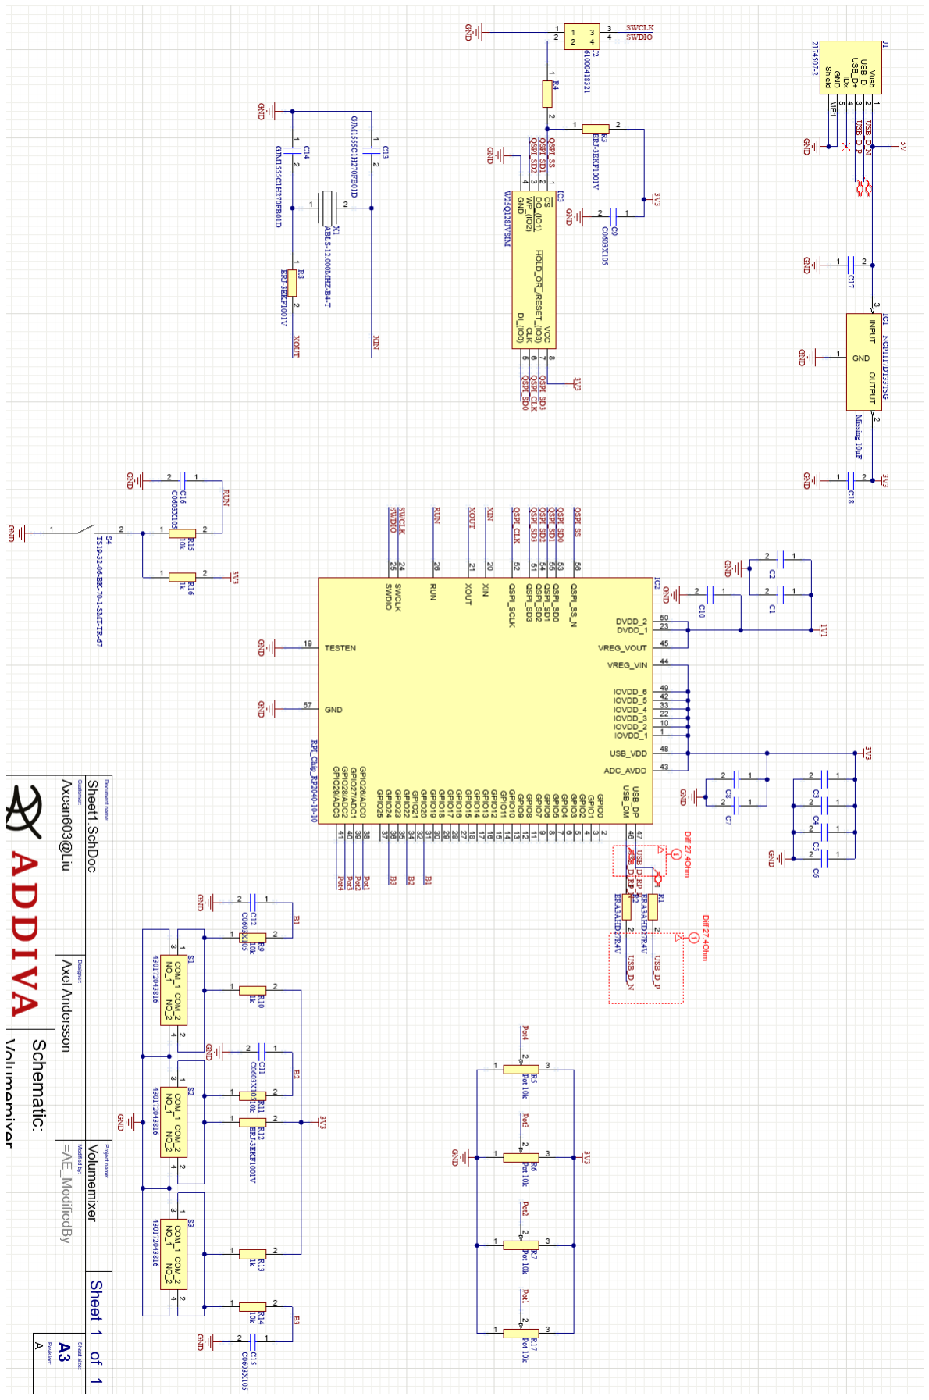
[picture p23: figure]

# Bilaga D Tidsplan och tidsrapportering

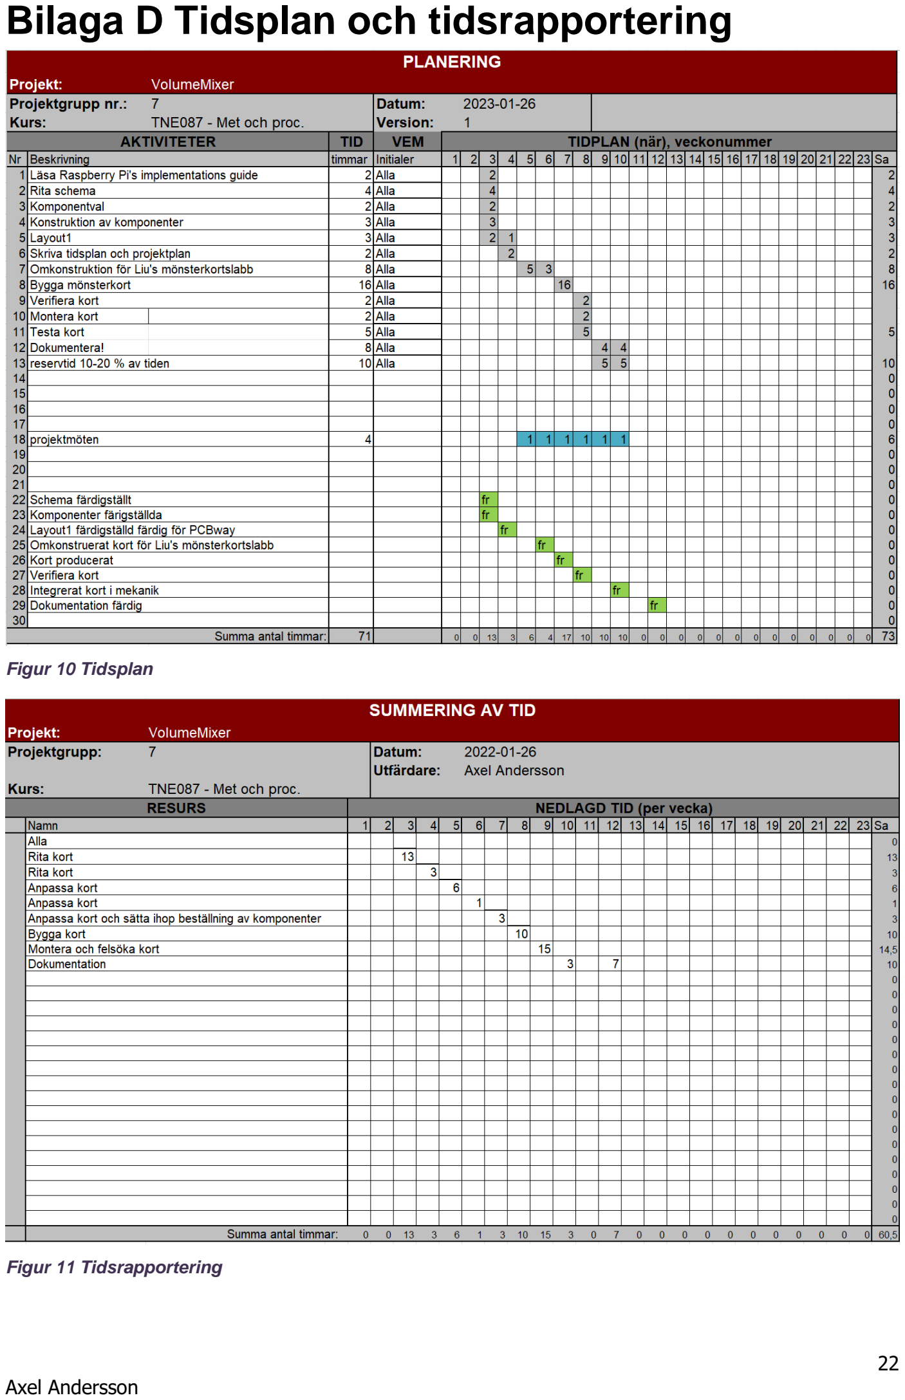
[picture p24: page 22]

Figur 10 Tidsplan

Figur 11 Tidsrapportering

# Bilaga E Status

Vem har gjort vad:
Axel Andersson har gjort allt.

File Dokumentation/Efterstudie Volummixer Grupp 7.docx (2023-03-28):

# Efterstudie

# Version 1.0

# VolumeMixer

Institutionen för teknik och naturvetenskap, campus Norrköping

# Gruppdeltagare

# Axel Andersson Axean603

Kursansvarig: Magnus Karlsson, magnus.b.karlsson@liu.se
Handledare: Magnus Karlsson, e-post-adress

# Innehållsförteckning

# 1 Tidsåtgång

## 1.1. Arbetsfördelning

Arbetsfördelningen har fungerat väl. Alla gruppmedlemmar har gjort vad de ska.

## 1.2. Tidsåtgång jämfört med planerad tid

Projektet har följt tidsplanen relativt väl. Planeringen försköts en vecka när det kom till att tillverka kortet då original planeringen krockade med arbetsbelastningen från andra kurser. Dock så blev det inget problem.

Mer tid tog till att förbereda inköp av komponenter än förväntat. Van vid att beställa och sedan skicka fakturan till kunden. Tiden brukar oftast vara mycket dyrare än komponenterna.

Tiden för konstruktion var rätt estimerad. Dokumentation har tagit lite längre tid än förväntat. I huvudsak p.g.a. försök att använda Latex.

Andra kommentarer är att det tog mindre tid att tillverka korten i mönsterkortslabbet än förväntat men det tog längre tid att montera och felsöka kortet än förväntat.

En bild som visar bord Automatiskt genererad beskrivning

Figur 1 Tidsrapportering

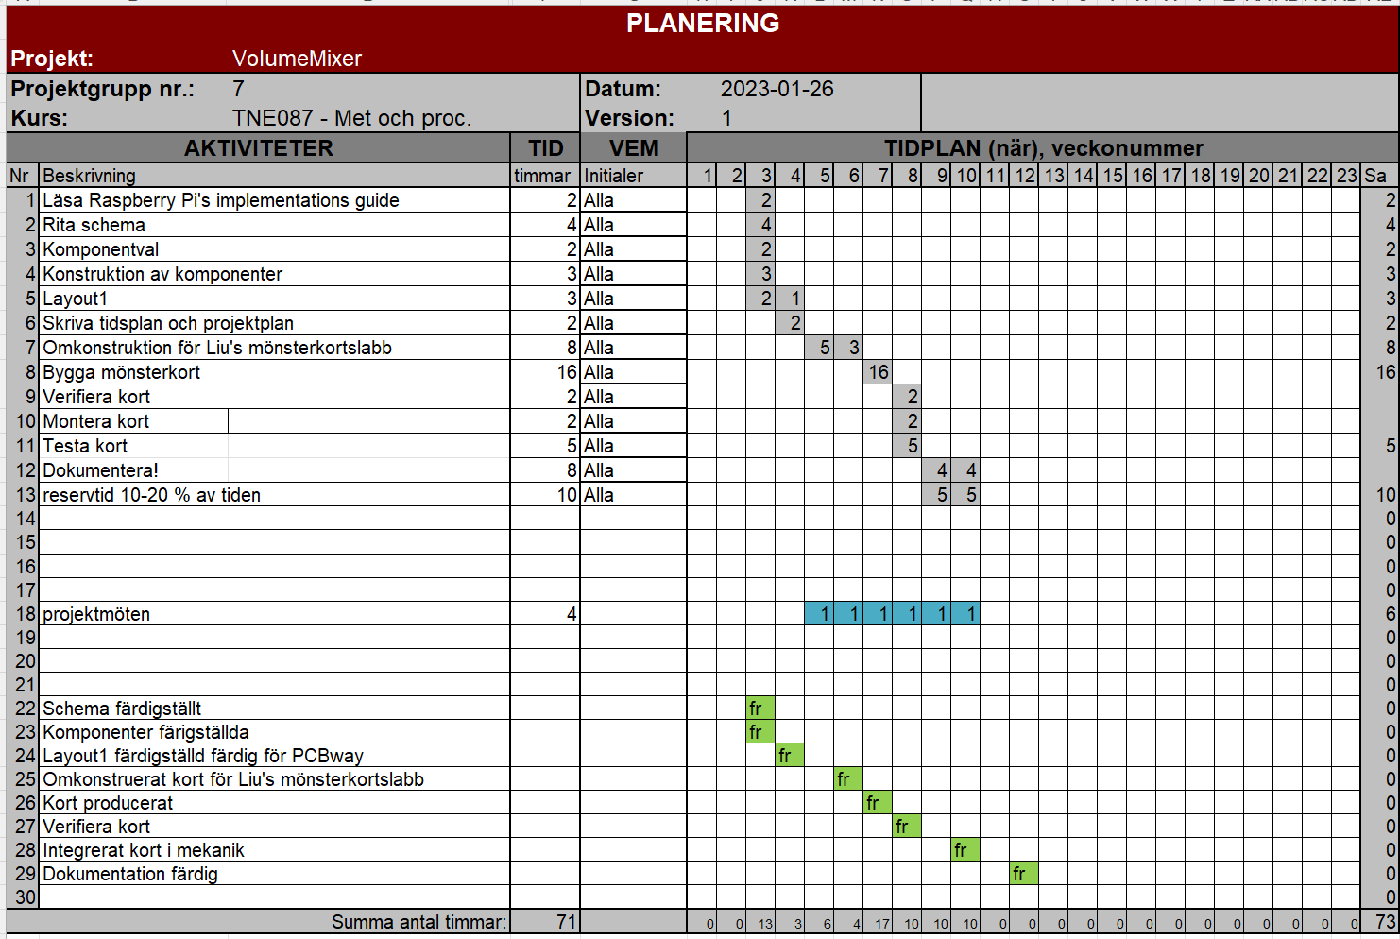
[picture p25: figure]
En bild som visar bord Automatiskt genererad beskrivning

Figur 2 Tidsplannering

# 2 Analys av arbete och problem

Analys av uträttat arbete och projektgenomförande.

## 2.1. Tekniska problem

Fotofilm skrivaren var ganska dåligt. Var största felkällan till förvrängningar mellan underlag och producerat kort.

Pick and place/lödmaskinen (Axel Andersson) matades med felaktigt underlag gällande mikrokontrollerns rotering.

## 2.2. Hur vi arbetade tillsammans?

Bra.

## 2.3. Hur använde vi projektdokumentationen?

Relativt standardprojekt att ta fram ett kort. Bra att veta vad som skall göras varje vecka och återkoppling gällande status. Projektplanen var kanske till mindre nytta men kan tänka mig att den är bra för de som tar fram sitt första kort för att samla tankarna kring vad som ska göras och hur. För större projekt kommer den också vara mer användbar. Alltid bra om slutkund och utförare är överens om vad som ska göras och kritiskt att det finns en plan på vad som ska levereras slutet av projektet.

# 3 Måluppfyllelse

I vilken grad har projektet lett till planerade mål.

## 3.1. Vad har uppnåtts

Allt

## 3.2. Hur fungerade slutprodukten

Bra

## 3.3. Hur har studiesituationen påverkat projektet?

Liten förskjutning i när kortet tillverkades p.g.a. kontrollskrivning och rapport i tillämpad matematik.

# 4 Sammanfattning med de viktigaste erfarenheterna

Fundera en gång till på rotation av komponenter. Lita inte på att du tidigare har gjort rätt. Mätt mer.

Ta bort fotofilmer innan etsning.

Se till att storleken på arket i plotterprogrammet är rätt och lägg inte underlaget för nära kanterna på arbetsytan.

TNE087 Grupp 7 LIPs

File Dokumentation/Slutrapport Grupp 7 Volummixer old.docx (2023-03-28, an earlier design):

Slutrapport Grupp 7

## VolumeMixer Table of Contents

# 1 Förkortningar

Förkortning | Betydelse
Liu | Linköpings Universitet
MCU | Mikrokontroller
GPIO | Generel Purpose Input Output
I/O | Input Output
LDO | Low-dropout regulator

# 2 Dokument Information

## 2.1 Version History

Revision | Date | Description
A | 2021-09-20 | Initial revision

## 2.2 Sammanfattning

I detta projekt har ett kretskort för utvecklats. Kortets funktion är att agera ett fysiskt gränssnitt för att kontrollera individuella applikationers ljudvolym som körs på en vanlig dator. Kortet ger också möjlighet att styra uppspelningen av media på datorn genom att ha tre knappar som kontrollerar paus/play, nästa låt och föregående låt.

För att utföra dessa funktioner så används en Raspberry RP2040 mikrokontroller som kommunicerar användarens kommandon till dator via USB. Närmare bestämt kommunicerar mikrokontrollern seriellt med ett Python skript som utför användarens kommandon.

För att kunna implementera RP2040 mikrokontrollern var en ovanligare monteringssätt tvungen att utföras för att arbeta runt de begränsningarna som finns i när mönsterkort görs i Linköpings Universitets mönsterkortslaboratorium. För att komma runt begränsningarna så ”dead bug” monterades mikrokontrollern, d.v.s. att kretsen lades på rygg och sedan drogs korta patchtrådar ut från kompentens paddar ut till paddar på mönsterkortet.

Efter kort felsökning av kortet efter montage startade mikrokontrollern och kortet fungerar som förväntat.

# 3 Introduktion

En stor del av jobbet som elektronikingenjör är att sluta kretsar på ett eller annat sätt (Oftast med fördel kontrollerat). Att sluta en krets kan göras på många olika sätt.

Det som har visat sig vara det dominerande alternativet idag är mönsterkort. En konstruktionsmetod som både har stora fördelar i produktions sammanhang samt tillåter den moderna elektronikingenjören konstruera mycket små kretsar av olika former och slag. Mönsterkort har också fördelen att man kan konstruera sina kretsar med mycket fin kontroll över geometrin av ledarna vilket kan användas till stor fördel då frekvenserna i signalerna stiger.

Som då blivande elektronikingenjörer är ett naturligt steg i utbildningen att vi ska bekanta oss med mönsterkortens konstruktion och produktion, vilket är målet och syftet med kursen ”Metoder och processer vid elektronikproduktion” (TNE087) som det här projektet är en del av.

Projektet har innefattat att konstruera en elektrisk konstruktion av valfri modell och sedan realisera den på ett mönsterkort.

Målet med det här projektet har mer specifikt varit att implementera Raspberry Pi Foundations MCU RP2040. MCUn mening är då att agera som fysiskt användargränssnitt för volymmixern som finns inbyggt i Windowsdatorer som ställer ljudvolymen för olika program som körs på datorn.

Kortet skulle också vara anpassat för att kunna tillverkas i Linköpings Universitets (Liu) mönsterkortslaboratorium. Mönsterkorten tillverkas där med hjälp av en etsande metod där en fotofilm används för att exponera valda delar utav en fotoresist.

Rekommenderade begränsningarna är kortfattat:

- Två lager
- 160x160mm
- Minsta ledarbredd 0.4mm
- Minsta clearance ledare 0.5mm
- Minsta borrdiameter 0.4mm

# 4 Att implementera Raspberry Pi foundations RP2040

## 4.1 Beskrivning av kretsen

Kortfattat är RP2040 en lågkostnads, högpresterande mikrokontroller.

Nyckelfunktioner är som följande:

- Dubbla Cortex M0+ kärnor, klockade upp till 133MHz
- 264kB av integrerat SRAM
- 30 multifunktionella GPIO (General Purpose Input Output)
- Dedikerad hårdvara för vanliga kringutrustningar
- 4 kanalers ADC (Analog digital konverterare)
- USB 1.1 Host/Device

Se figur xx nedan för en översikt av RP2040 interna uppbyggnad.


Figur 1 RP2040's interna uppbyggnad

## 4.2 Nödvändigheter för RP2040

För att framgångsrikt implementera RP2040 kretsen krävs tre saker.

- Spänningsmatning
- SPI-minne
- Kristalloscillator

Mer ingående beskrivningar av vad som krävs kan läsas nedan

### 4.2.1 Spänningsmatning

RP2040 kräver två spänningar 3V3 (för I/O) och 1V1 (för kretsens digitala kärna). Praktiskt nog finns en inbyggd LDO (Low-dropout regulator) som generar 1V1 till kretsen.

### 4.2.2 Inkommande matning

I och med att den här kretsen syfte att agera fysiskt gränssnitt till en dator så kommer kretsen alltid vara inkopplad till en dator och kommer därför alltid att matas med 5V. Den inkommande 5V kan sedan användas för att generera 3V3 som kan användas för att driva RP2040 kretsen.

För att generera 3V3 i den här konstruktionen användes en LDO närmare bestämt användes onsemi’s NCP1117ST33T3G dels för att den rekommenderas i Raspberry Pi foundation’s ”hardware design with RP2040” och för att den råkade finns i Litheels lager. Kretsen skall enligt dess datablad ha en kondensator på 10µF kopplat till inkommande spänning och en kopplad till utgående spänning.

### 4.2.3 Avkoppling kondensatorer

Till RP2040 rekommenderas det att det finns avkopplingskondensatorer i närheten av paddarna för inkommande spänningsmatning till kretsen. Generellt är rekommendationen 100nF vid varje padd samt 1µF i närheten av padden till LDOn som genererar 1V1. 1µF rekommenderas också finns i närheten av utgången från LDOn. Dessa kondensatorer har två grundläggande funktioner, att filtrera ut brus som finns på spänningsmatningen och vara en källa till energi som RP2040 kretsen kan använda när den tillfälligt använder mycket energi till exempel vid omslag på en utgång.

### 4.2.4 SPI-minne

För att kunna spara programkod som mikrokontrollern kan köra så krävs ett externt minne. I det här fallet användes ett W25Q128JVS vilket är ett quad SPI flash minne på 128Mbit. Detta minne valdes i och med att det användes i Raspberry Pi foundation’s ”hardware design with RP2040” implementation.

### 4.2.5 Kristalloscillator

Tekniskt sätt behövs inte en extern oscillator för RP2040 skall fungera utan den har en inbyggd oscillator men i och med att den inte är speciellt stabil rekommenderar Raspberry Pi foundation att en extern klockkälla bör användas. I det här fallet användes en ABLS-12.000MHZ-B4-T vilket är en 12MHz kristalloscillator. Den implementerades i enlighet med Raspberry Pi foundation’s ”hardware design with RP2040” rekommendationer.

## 4.3 Partikulära detaljer relaterat med det här kortets funktion

### 4.3.1 USB

RP2040 har möjlighet att kommunicera över USB i fullspeed(12Mbps) och lowspeed(1.5Mbps) som antingen host eller device. För det här projektet så utnyttjades det genom att RP2040n konfigurerades att agera som device och kommunicera med ett Python skript på värddatorn med hjälp av en virtuell serieport som kommuniceras över USB. Ytterligare så programmeras kretsen enklast över USB så en fungerande USB implementation var ett krav.

För att USB skall fungera som förväntat så finns vissa krav kortet. Närmare bestämt bör ledarena för USB’s data par dels vara terminerade med ett varsitt 27.4Ohm motstånd samt att parets ledare skall ha en differentiell impedans på 90Ohm.

### 4.3.2 I/O som används

Totalt kommer 7 stycken I/O pinnar att användas. De fyra pinnarna som är kopplad till de 4 kanalerna på den interna ADCn i RP2040n kommer att kopplas till varsin potentiometer och kommer att användas för att kontrollera volymen för fyra olika applikationer som kör på värddatorn. Tre stycken I/O pinnar kommer vara kopplade till tre stycken tryckknappar.

Referenser xxx

# 5 Projektets genomförande

## 5.1 Konstruktion av schema

Schemat konstruerades i enlighet med de krav som detaljeras under rubriken 4 Att implementera Raspberry Pi foundations RP2040. Majoriteten av schemasymbolerna och PCB footprintsen importerades med hjälp av Altium Library Loader för att spara tid. En del av symbolerna så som symbolen för RP2040 modifierades dock för att öka läsbarheten i schemat. Även en del av PCB footprinten modifierades för att korrigera fel från den troligen automatiserade processen som Altium Library Loader använder för att ska symbolerna och footprinten.

## 5.2 Konstruktion av layout

Två varianter konstruerades, en variant anpassad att tillverkas av ett vanligt produktionshus i det här fallet JLCpcb och en variant anpassad för att tillverkas i Lius mönsterkortslaboratorium. Storleken på kortet samt var potentiometrarna, monteringshål och tryckknapparna är placerades bestämdes utifrån den redan tillverkade mekaniken.

### 5.2.1 Variant anpassad för JLCpcb

För JLCpcb konstruerades en variant på kortet som var anpassad för deras enklaste två lagers kort. Exakta begränsningar kan läsas på JLCpcbs hemsida.

### 5.2.2 Variant anpassad för Lius mönsterkortslaboratorium

Att anpassa kortet för att kunna tillverkas på Lius mönsterkortslaboratorium var en större utmaning ty begränsningarna här större och marginalerna måste vara större för att lyckas producera ett fungerande mönsterkort.

Den största svårigheten med att anpassa den här konstruktionen att vara producerabar i Lius mönsterkortslaboratorium var hur footprinten för RP2040 mikrokontrolern skulle utformas. RP2040 kretsen är i en så kallad QFN-56 kapsling som är 7x7mm stor med en pitch på 0.4mm mellan benen. Att lyckas tillverka det footprintet framgångsrikt i Lius mönsterkortslaboratorium hade varit en stor utmaning så istället togs beslutet att kretsen skulle monteras i ”dead bug” stil d.v.s. att kretsen läggs på rygg och små patch trådar dras från komponentens ben till paddar på kortet. På det sättet kan större geometrier göras på kortet och på så sätt göra kortet enklare att producera.

För att framgångsrikt kunna ”dead bug” montera kretsen gjordes även en del anpassningar på support kretsar och komponenter. Den största anpassningen var hur avkopplingskondensatorerna placerades och monterades. Istället för att bara montera dem direkt på kortet ställdes de på högkant längs med kanten på mikrokontrollern och då kondensatorer i storleken 0402 användes var kondensatorerna lika långa som mikrokontrollern var tjock vilket gjorde inkopplingen av kondensatorerna väldigt enkel. Ytterligare modifierades vissa av footprinten för kondensatorerna för att kunna montera flera kondensatorer mot samma padd för att passa in på de pinnarna där flera spänningsmatningspinnar var placerade sida vid sida.

## 5.3 Test av kort efter tillverkning

### 5.3.1 Omonterat kort

Följande steg skall tas vid verifikation av omonterat kort.

- Alla ledare skall testas med en ohmmeter för att se att ledaren är kontinuerlig som förväntad.
- Alla ledare skall testas med en ohmmeter mot lämpliga närliggande ledare för att se att det inte finns några oväntade kortslutningar
- En visuell inspektion skall genomföras för att verifiera att mönsterkortet ser välskapt ut och inga uppenbara fel kan ses.

### 5.3.2 Monterat kort innan uppstart

Följande steg skall tas vid verifikation av monterat kort innan uppstart.

- Alla ledare skall testas med en ohmmeter för att se att ledaren är kontinuerlig som förväntad och att lödningarna har utförts som de ska.
- Alla ledare skall testas med en ohmmeter mot lämpliga närliggande ledare för att se att det inte finns några oväntade kortslutningar
- En visuell inspektion skall genomföras för att verifiera att kretskortet ser välskapt ut och inga uppenbara fel kan ses.

### 5.3.3 Monterat kort efter uppstart

Följande steg skall tas vid verifikation av monterat kort innan uppstart.

- Följande spänningsmatningarna skall mätas: 5v 3v3 samt 1v1.
- Kristalloscillatorn skall mätas för att verifiera att klockan har startat och har förväntad frekvens
- Kortet skall kopplas in till dator och programmeras
- Kortets funktioner skall verifieras genom att köra det förväntade programmet som kommunicerar potentiometrarnas läge samt tryckknapparnas status till värddatorn.
- Kortet skall monteras i mekaniken för att se att det passar

## 5.4 Felsökning av kortet

### 5.4.1 Vid första start

Stor ström gick. Kortslutning mellan 3v3 och jord. Försökte med värmekamera identifiera var. Var dock svårt att se exakt var men värmekameran gav ett område. Kapade därefter ledare för att undersöka närmare. Hittade en lödbrygga vid en av avkopplingskondensatorerna.

### 5.4.2 Vid andra start

Stor ström gick fortfarande. Kopplade förbi LDOn och matar med 3v3 direkt. Kortet drar mer rimligt ström. Ca 7mA. Inget händer och 1v1 generas inte som den ska. Testade experimentera med hur run signalen görs. Inget resultat. Bekräftar därefter att alla signaler är inkopplade som förväntat. Inget resultat.

Gör därefter en gissning att MCUn har dött vid experiment. Byter MCUn. Monterar den med absolut minsta möjliga inkopplingar. Endast matningar, klocka samt run och testenable inkopplat.

### 5.4.3 Verifikation av inkoppling efter montage

Mäter då resistansen mellan 3v3 och GND 0.8OOhm. Kopplar lös GND kopplingen till kretsen och mäter mellan GND benet på kretsen och 3v3 på kretsen. Fortfarande 0.8Ohm.

Mäter på en ny omonterad krets. Fortfarande 0.8Ohm. Mäter där efter mellan benen för spänningsmatningen för 3v3. De bör vara ihopkopplade internt. Konstaterar då att kretsen är monterad 90 grader fel. Vid montage vändes kretsen kring fel axel.

### 5.4.4 Justerar monteringen av kretsen

Verifierar att kretsen var rätt vriden och att inget är kortslutet. Kortet startar som förväntat. 1v1 genereras som förväntat och klockan går. Kretsen svarar också som förväntat när den kopplas till en dator. Programmering tar dock inte.

### 5.4.5 Verifikation av inkoppling av SPI-minne

Konstaterar att SD3 och SD0 har bytt plats vid montering. Efter korrigering kan kortet programmeras och tryckknapparna samt potentiometrarna ger utslag som förväntat.

När ni redogör för projektet så kan ni välja rubriker som det passar. Design, layout, vad man valde att tillverka, utformning av test etc.

o Ibland känt som ”Metod”, fast mest i vetenskapliga studier med mera. I utvecklingssammanhang är det mera fokus på vad man tagit fram, hur och varför man gjort olika val. Tänk ”genomförande”.

o Här är det fokus på erat arbete, vad ni har gjort, hur ni har gjort det. Om man har valt något av något speciellt skäl.

o Kan delas in på många olika sätt. Finns olika tänkbara rubriker. Välj så att det passar erat arbete och vad ni tar upp.

o Ni ska inte gå igenom PCB-processen. Med tillverkning ovan menas hur ert mönsterkort blev.

# 6 Resultat

## 6.1 Omonterade kort tillverkade av JLCpcb

Se figur 2 nedan för resultat

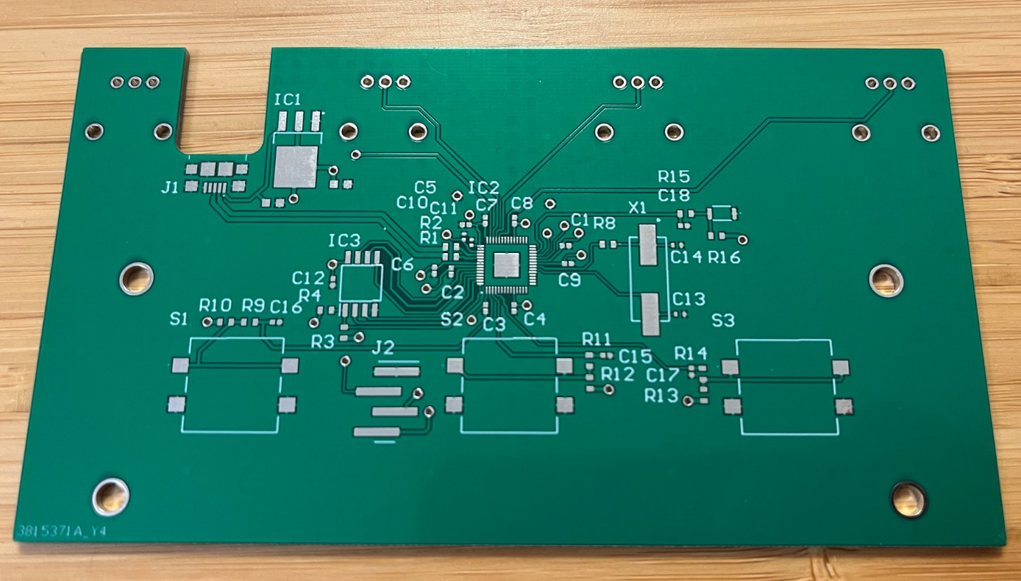
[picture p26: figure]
En bild som visar text, elektronik, krets Automatiskt genererad beskrivning

Figur 2 Mönsterkort producerat av JLCpcb

## 6.2 Monterade kort tillverkade i Lius mönsterkortslaboratorium

Se figur 3 och 4 nedan för resultat

En bild som visar text, elektronik, krets Automatiskt genererad beskrivning

Figur 3 Monterat kort tillverkat i Lius mönsterkortslaboratorium

En bild som visar text Automatiskt genererad beskrivning

Figur 4 "Dead bug" monterad krets

# 7 Diskussion

## 7.1 Varför kortet inte riktigt blev som underlaget

Som kan ses på några av ledarna i figur 3 så finns en del förvrängningar i det slutgiltiga resultatet.

Den största faktorn för varför de blev så pass förvrängda i visa områden är troligen att fotofilmen blev förvrängd när den skrevs ut. Det var stora problem med att få skrivaren att fungera när fotofilmen skulle göras. Hade både problem med att få den att skriva ut överhuvudtaget och när den väl skrev ut var allt förskjutet i y-led. Nu visade det sig att dessa förvrängningar inte var ett problem och kortet fungerade som förväntat.

# 8 Slutsats

Det går att implementera en RP2040 mcu på ett mönsterkort tillverkat i Lius mönsterkortslabaratorium om konstruktionen anpassas till begränsningarna som finns och en del av det mer finkänsliga geometrierna görs i form av patcharbete i stället.

Kortet fungerade när det var korrekt monterat som förväntat och konstruktionen når de krav som var ställda.

Author: Axel Andersson Slutrapport Grupp 7 VolumeMixer Security: Date: 23-3-28 Revision: A

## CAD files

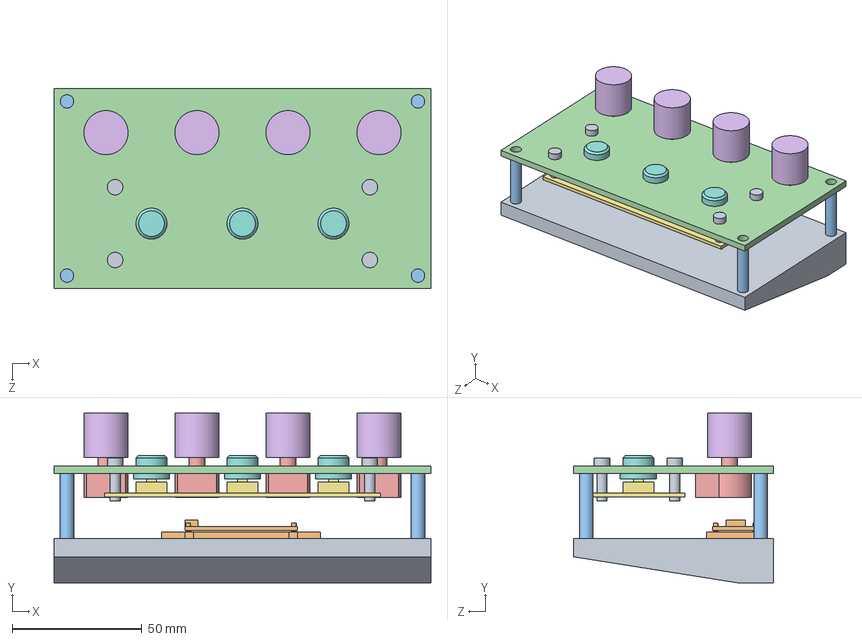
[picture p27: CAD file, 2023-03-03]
CAD/Assem.SLDASM
145.0 x 65.2 x 77.0 mm
Backplate
Arduino Nano
spacer big x 4
Frontplate
Pot x 4
Ratt x 4
Button board
Knapp x 3
Skrew M4 12mm x 4
Adapter

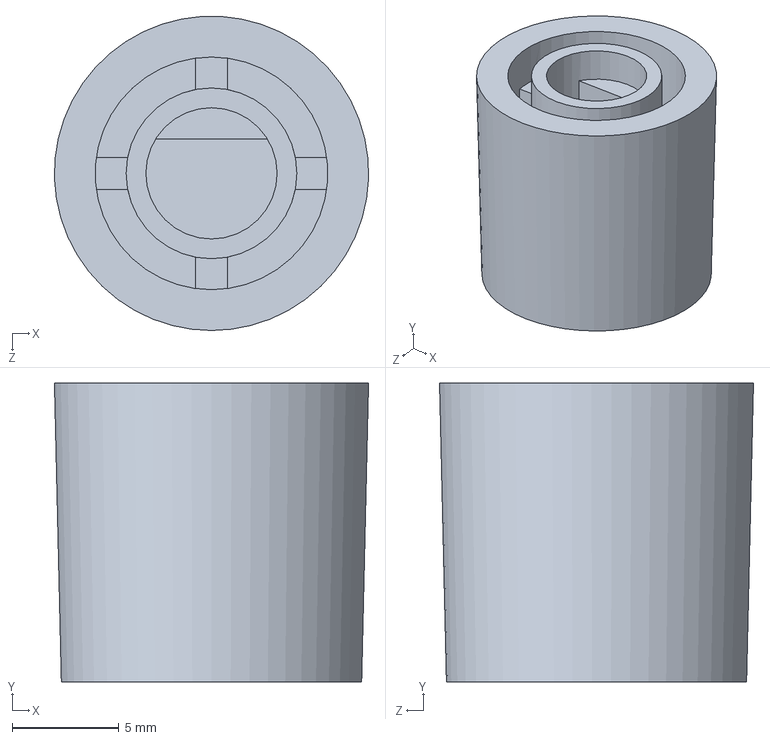
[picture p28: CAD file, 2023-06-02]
CAD/Pot adapter.SLDPRT
14.7 x 14.0 x 14.7 mm

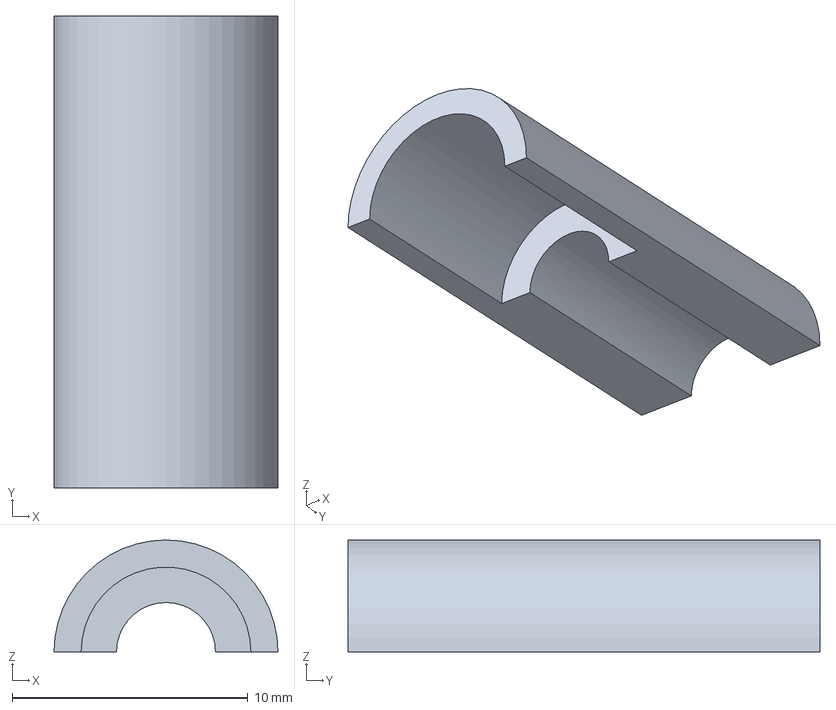
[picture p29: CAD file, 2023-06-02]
CAD/Strain relief.3MF
9.50 x 20.0 x 4.75 mm

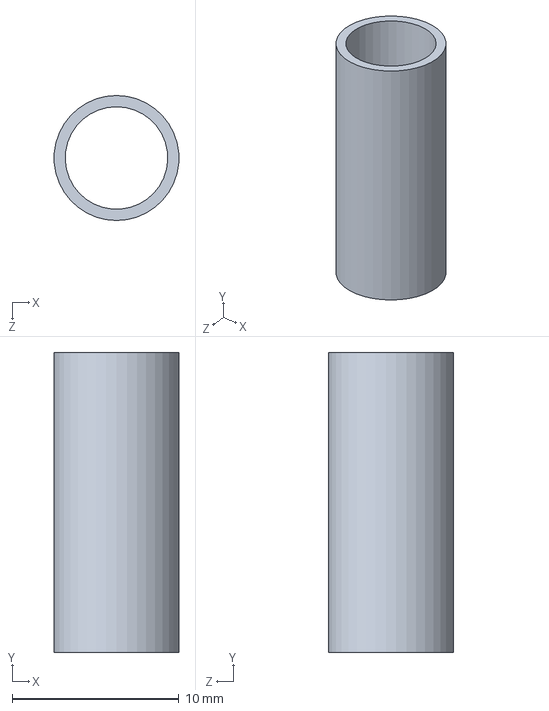
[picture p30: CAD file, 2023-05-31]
CAD/Standoff long.SLDPRT
7.47 x 18.0 x 7.50 mm

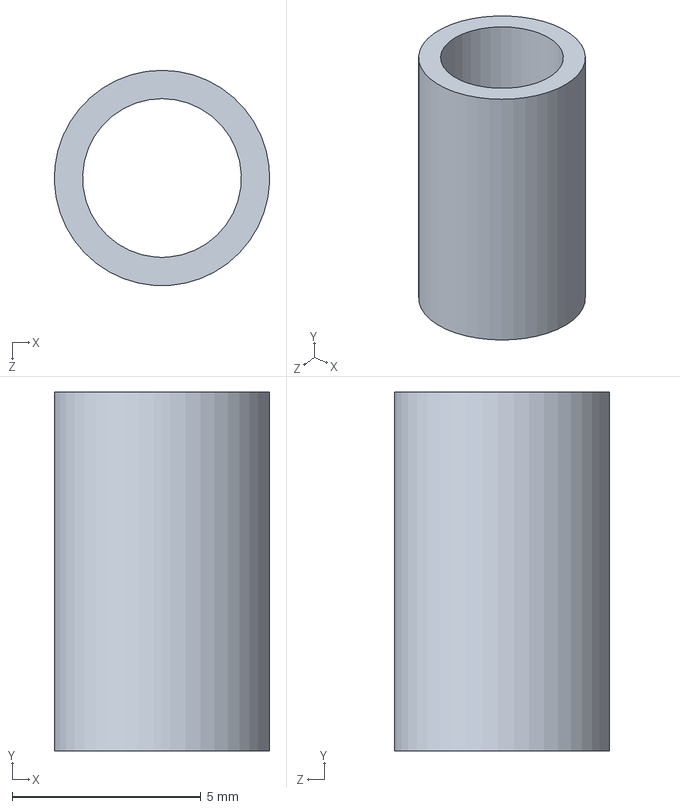
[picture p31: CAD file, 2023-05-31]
CAD/Standof 4mm 9mm5.SLDPRT
5.70 x 9.50 x 5.70 mm

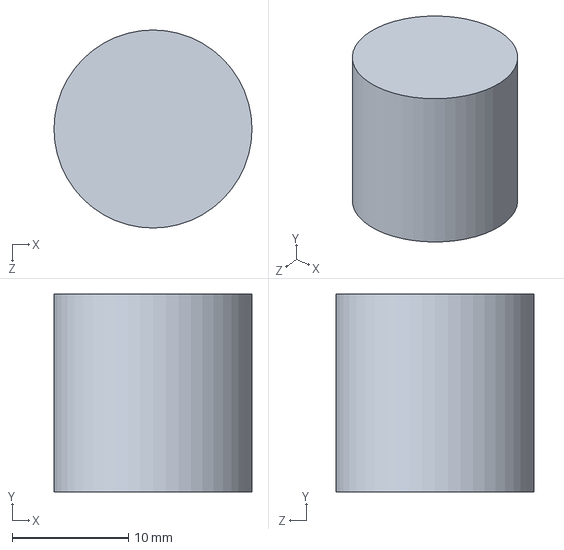
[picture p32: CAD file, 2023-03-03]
CAD/Ratt.SLDPRT
17.0 x 17.0 x 17.0 mm

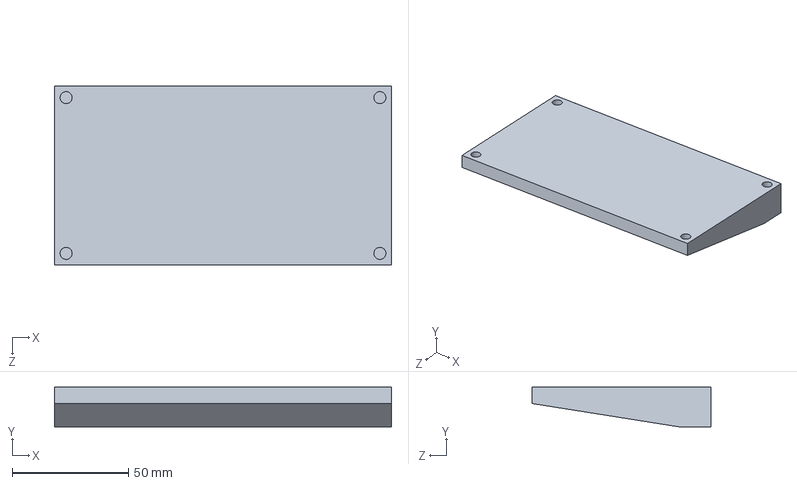
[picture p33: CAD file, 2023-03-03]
CAD/Backplate in sw2020.SLDPRT
145.0 x 17.0 x 77.0 mm

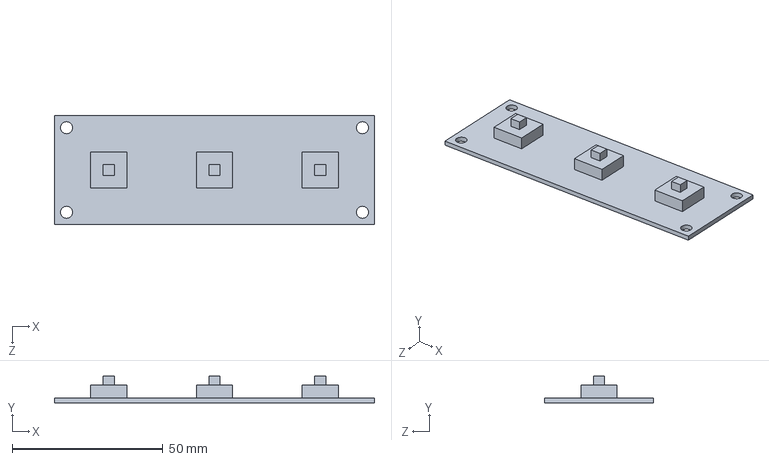
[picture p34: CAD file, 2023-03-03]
CAD/Button board.SLDPRT
106.0 x 8.90 x 36.0 mm

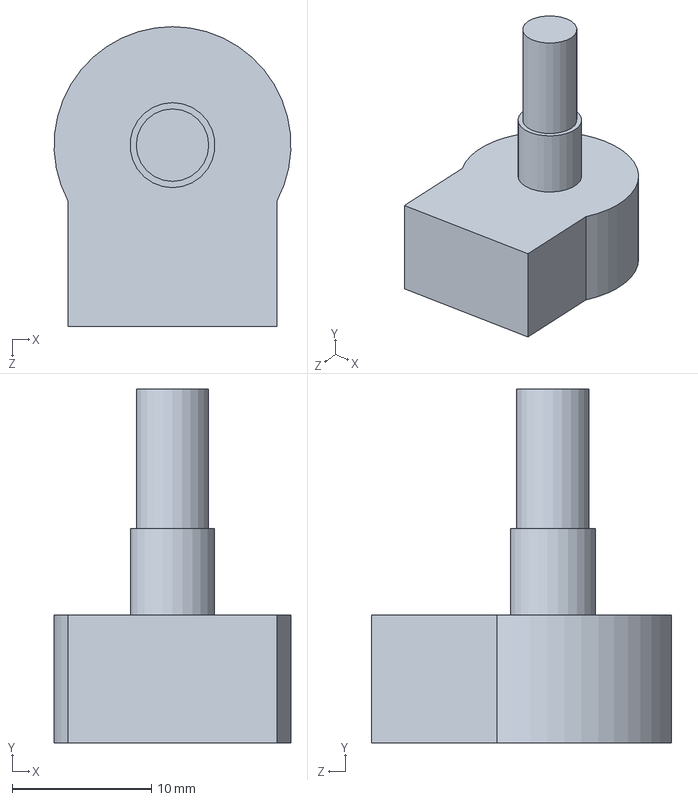
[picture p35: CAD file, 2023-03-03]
CAD/Pot.SLDPRT
17.0 x 25.4 x 21.5 mm

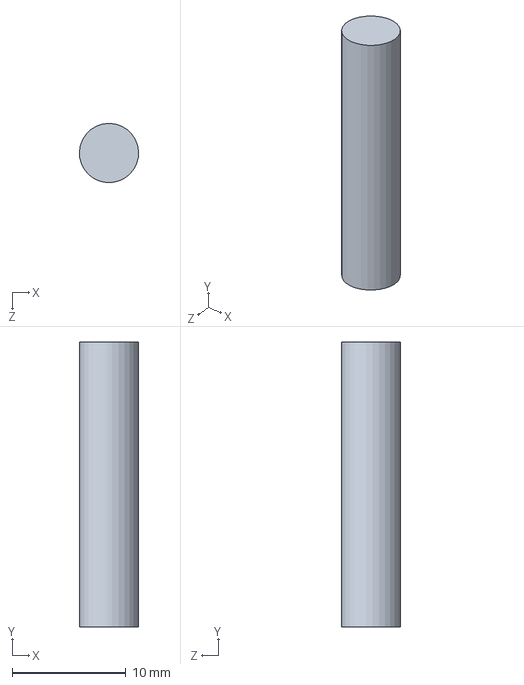
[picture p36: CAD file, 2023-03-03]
CAD/spacer big.SLDPRT
5.19 x 25.0 x 5.20 mm

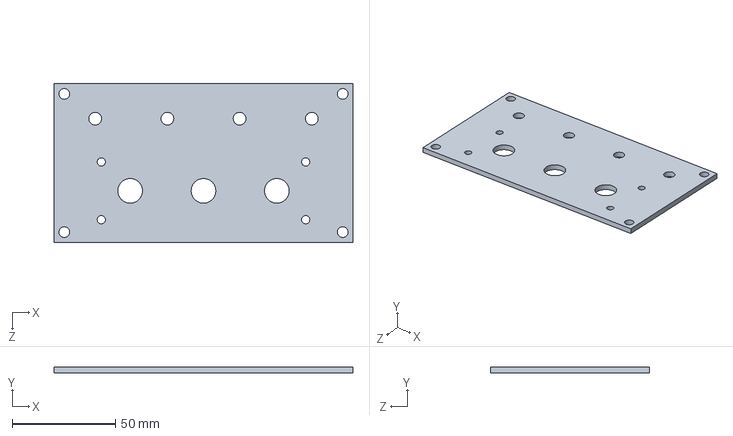
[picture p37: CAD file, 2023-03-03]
CAD/Frontplate in sw2020.SLDPRT
145.0 x 3.00 x 77.0 mm

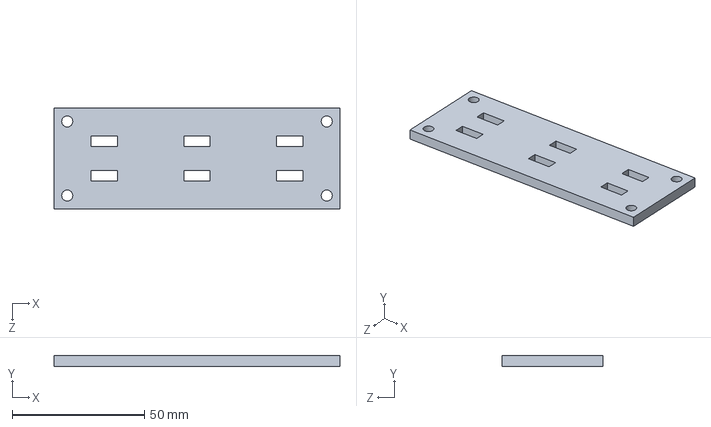
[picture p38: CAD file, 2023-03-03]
CAD/Keyplate 4mm.SLDPRT
108.0 x 4.00 x 38.0 mm

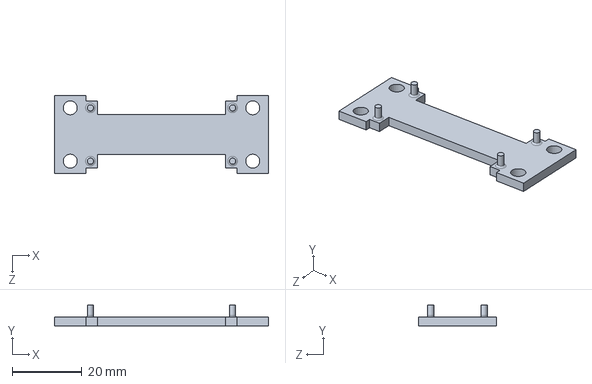
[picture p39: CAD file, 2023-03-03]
CAD/Adapter.SLDPRT
61.2 x 6.00 x 22.2 mm

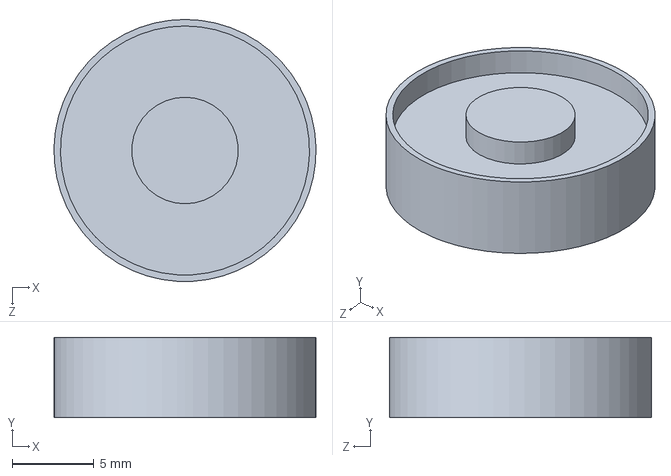
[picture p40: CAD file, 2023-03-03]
CAD/Button riser.SLDPRT
16.0 x 4.90 x 16.0 mm

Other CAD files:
CAD/Backplate.SLDPRT
CAD/Frontplate.SLDPRT
CAD/B3F-5050.SLDPRT
CAD/Knapp alt.SLDPRT
CAD/Adapter.STL
CAD/Arduino Nano.SLDPRT
CAD/Backplate 2D.SLDDRW
CAD/Button riser.3MF
CAD/Frontplate 2D.SLDDRW
CAD/Keyplate 3mm.STL
CAD/Keyplate 4mm.STL
CAD/Knapp 2D.SLDDRW
CAD/Knapp.SLDPRT
CAD/PCB.SLDPRT
CAD/PCB.x_t
CAD/Pot adapter.3MF
CAD/Skrew M4 12mm.SLDPRT
CAD/Spacer small.SLDPRT
CAD/Standof 4mm 9mm5.3MF
CAD/Standoff long.3MF
CAD/outline.DWG
CAD/outline.SLDPRT

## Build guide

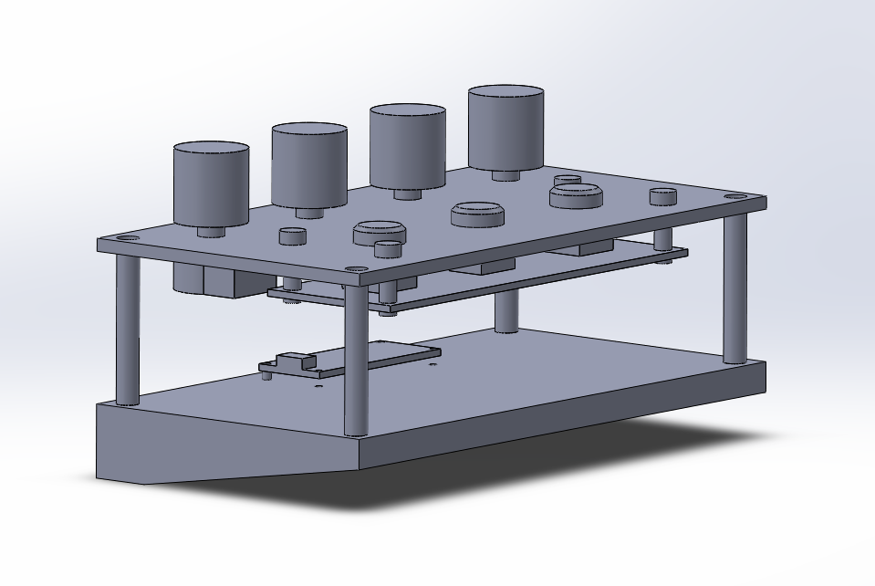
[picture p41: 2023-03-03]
CAD/Bilder/Assembly2.PNG

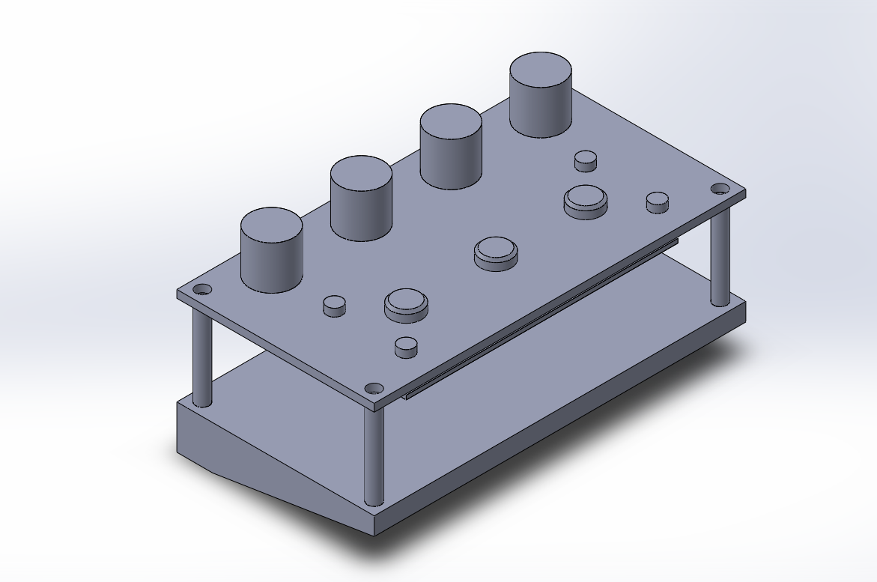
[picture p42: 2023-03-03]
CAD/Bilder/Assembly.PNG

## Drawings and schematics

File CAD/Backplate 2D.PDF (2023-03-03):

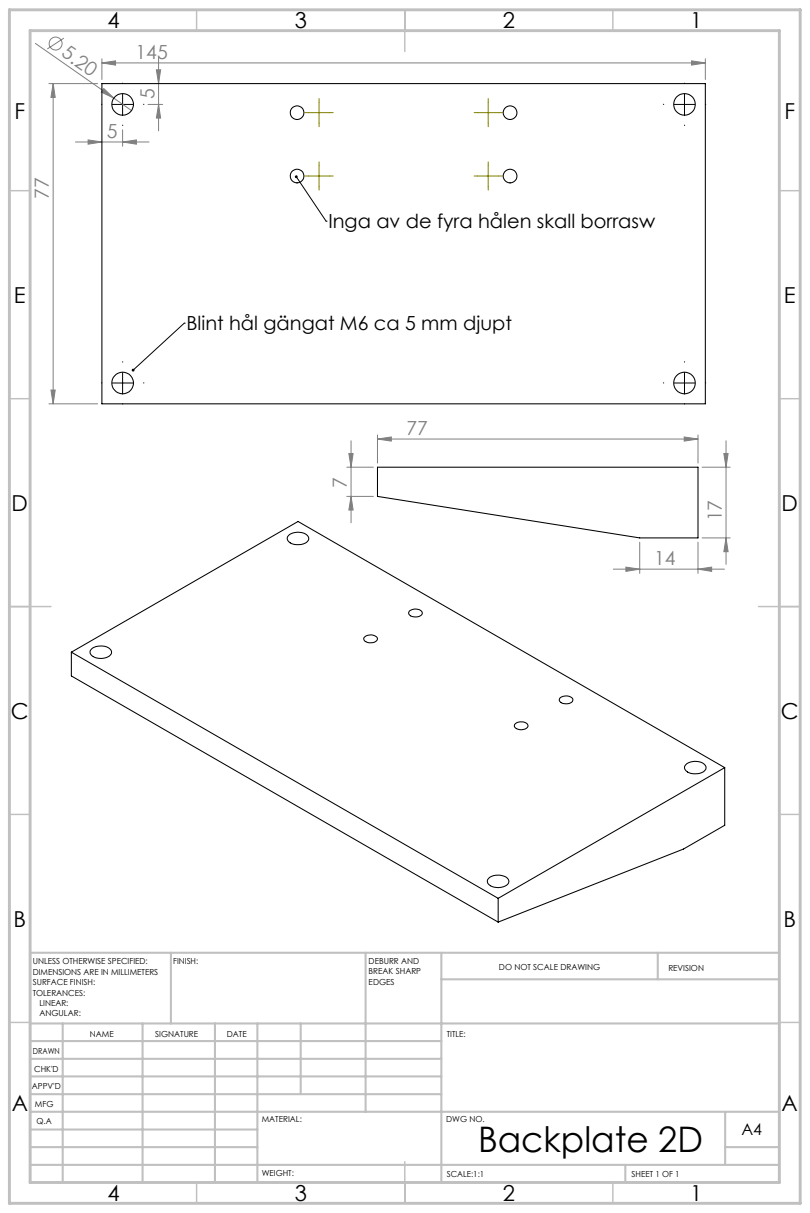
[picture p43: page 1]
FINISH:; DEBURR AND; BREAK SHARP; DO NOT SCALE DRAWING; REVISION; SCALE:1:1; SHEET 1 OF 1

Inga av de fyra hålen skall borrasw 7

Blint hål gängat M6 ca 5 mm djupt

UNLESS OTHERWISE SPECIFIED:
DIMENSIONS ARE IN MILLIMETERS
SURFACE FINISH:
TOLERANCES:
LINEAR:
ANGULAR:

NAME | SIGNATURE | DATE | | | | TITLE:

DRAWN
CHK'D
APPV'D
MFG
Q.A | | | | MATERIAL: | DWG NO. Backplate 2D | A4

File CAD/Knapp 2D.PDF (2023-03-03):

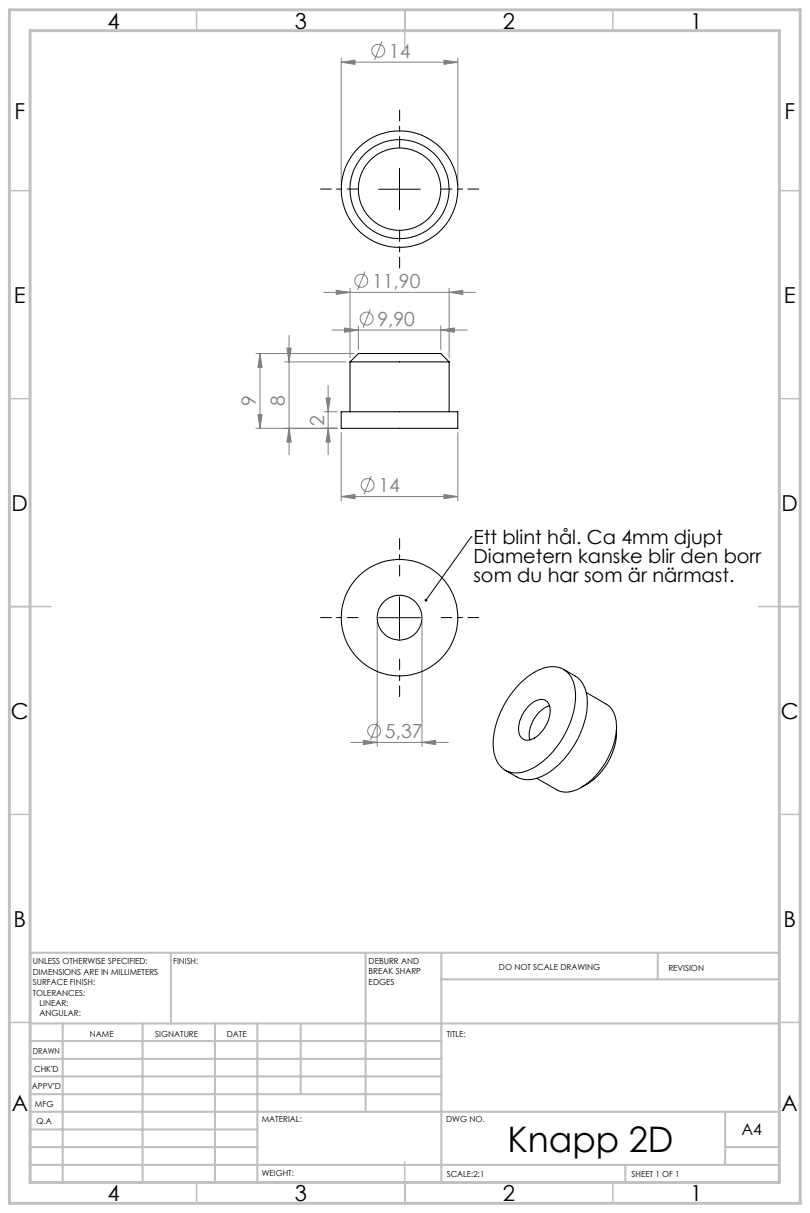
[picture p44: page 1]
FINISH:; DEBURR AND; BREAK SHARP; DO NOT SCALE DRAWING; REVISION; SCALE:2:1; SHEET 1 OF 1

Ett blint hål. Ca 4mm djupt
Diametern kanske blir den borr
som du har som är närmast.

UNLESS OTHERWISE SPECIFIED:
DIMENSIONS ARE IN MILLIMETERS
SURFACE FINISH:
TOLERANCES:
LINEAR:
ANGULAR:

NAME | SIGNATURE | DATE | | | | TITLE:

DRAWN
CHK'D
APPV'D
MFG
Q.A | | | | MATERIAL: | DWG NO. Knapp 2D | A4

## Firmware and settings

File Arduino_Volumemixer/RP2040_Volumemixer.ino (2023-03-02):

/////////////////////////////////////
////This is a Arduino program used to read values from a few pots,
////the state of a few buttons and send the read information over
////serial to a python script. The python script uses the read
////information to change volume of programs runing on the
////computer. The buttons is used as media controls.
////Uses bounce2 https://github.com/thomasfredericks/Bounce2
////By Axel Andersson 2020
/////////////////////////////////////

/////////////////////////////////////
////The informations sent over serial if structured as such
////X Y where X is the channel information used to determine which
////programs volume should be changed. Y is in this chase the volume
////in the format 0.5 eg 1 0.5 would be channel 1 at 50% volume
////A special case is if X = 0 it indicates that a button
////has been pressed and Y is now which button.
/////////////////////////////////////

/////////////////////////////////////
////Pins
/////////////////////////////////////
//Digital input pins used GPIO18, GPIO20, GPIO24
#include <Bounce2.h>

Bounce button0 = Bounce();
Bounce button1 = Bounce();
Bounce button2 = Bounce();

const float potPin[4] = {26, 27, 28, 29}; //Analog input pins GPIO26-29
float potValue[4]; //Current potvalues
float oldPotValue[4] = {0,0,0,0}; //Previus potvalues

/////////////////////////////////////
////Setup
/////////////////////////////////////

void setup() {
  pinMode(26, INPUT);
  pinMode(27, INPUT);
  pinMode(28, INPUT);
  pinMode(29, INPUT);
  //pinMode(D11, INPUT_PULLUP);
  //pinMode(D7, INPUT_PULLUP);
  //pinMode(D4, INPUT_PULLUP);

  button0.attach(18,INPUT_PULLUP);
  button1.attach(20,INPUT_PULLUP);
  button2.attach(24,INPUT_PULLUP);// Attach the debouncer to a pin with INPUT_PULLUP mode
  button0.interval(10); // Use a debounce interval of 25 milliseconds
  button1.interval(10);
  button2.interval(10);

  Serial.begin(9600); //Start Serial
}

/////////////////////////////////////
////Loop
/////////////////////////////////////

void loop() {

  updateButtons();

  for (int i = 0; i < 4; i++) {
    getPotValue(i);
    //Checks to make sure pot values are valid
    //Eg not same as old, not 1, not 0
    if (potValue[i] != oldPotValue[i])  { //Compare old to new and new to 1 and 0
       sendPotValue(i);
    }
  } // Gets values for all pots

  delay(60);
}

/////////////////////////////////////
////Functions
/////////////////////////////////////


void getPotValue(int i) {
  static float potValueExp;
//  potValue[i] = (float( constrain(map(analogRead(potPin[i]), 0, 1023, 0, 102), 0, 100))/100);

  //read analog signal and map to value between 0-100
  potValueExp = float(constrain(map(analogRead(potPin[i]), 0, 1023, 102, 0), 0, 100));
  potValue[i] = ((0.01*potValueExp*potValueExp)/100);
};

void updateButtons() {
  button0.update(); //updates the buttons states
  button1.update();
  button2.update();
  if (button0.fell()) {
    sendButton(0);
  }
  if (button1.fell()) {
    sendButton(1);
  }
  if (button2.fell()) {
    sendButton(2);
  }
};

void sendPotValue(int l) { //Sends potValues over serial to python script
  Serial.print(l+1);
  Serial.print(" ");
  Serial.println(potValue[l]);
  oldPotValue[l] = potValue[l];
};

void sendButton(int l) {
  Serial.print("0 ");
  Serial.println(l);
};

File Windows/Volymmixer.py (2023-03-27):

from infi.systray import SysTrayIcon
import serial
import serial.tools.list_ports
import os
import ctypes
import codecs
import win32ui
import win32gui
import win32api
import win32process
from time import sleep
from infi.systray import SysTrayIcon
from win32con import VK_MEDIA_PLAY_PAUSE, VK_MEDIA_NEXT_TRACK, VK_MEDIA_PREV_TRACK, KEYEVENTF_EXTENDEDKEY
import pycawcalls

#Script for controling the volume for indvidual programs where the volume is
#controled by a arduino communicating using serial. pidNano might be needed to
#be changed to make the script work.
#By Axel Andersson 2020

#Script is developed for python 3.8.1
#packages needed to be installed with pip
#infi.systray
#pyserial
#pywin32
#pycaw https://github.com/AndreMiras/pycaw more install instructions in the readme

shouldIQuit = False #

pidNano = 192 #product id for the arduino nano which is used to identify the correct COM-port
#product id. Unique for diffrent kind of devices might be needed to be modified. Use following the following code to find pid
#portList = list(serial.tools.list_ports.comports())

# for port in portList:
#     print(port.pid)
#Finds local dir for nircmd.exe
#os.chdir(os.path.dirname(os.path.realpath(__file__)))

def on_quit(systray): #What happens when quit is pressed in the taskbar
    global shouldIQuit
    shouldIQuit = True

def on_about(systray): #About tab
    ctypes.windll.user32.MessageBoxW(None, u"A program that communicates with a dedicated volume mixer \nWriten by Axel Andersson 2020 ", u"About", 0)

def startTrayIcon(): #Starts systemtray icon
    icon_path = os.path.join(os.path.dirname(os.path.realpath(__file__)),"Volume mixer icon.ico")

    shutdown_called = False #Do know

    menu_options = (("About", None, on_about),)
    systray = SysTrayIcon(icon_path, "Volume Mixer", menu_options, on_quit)
    systray.start()

def nextTrack():
    win32api.keybd_event(VK_MEDIA_NEXT_TRACK, 0, KEYEVENTF_EXTENDEDKEY, 0)

def pauseTrack():
    win32api.keybd_event(VK_MEDIA_PLAY_PAUSE, 0, KEYEVENTF_EXTENDEDKEY, 0)

def prevTrack():
    win32api.keybd_event(VK_MEDIA_PREV_TRACK, 0, KEYEVENTF_EXTENDEDKEY, 0)



def findArduinoNanoPort(pidNano): #Finds the comport the arduino is connected to
    comport =''

    portList = list(serial.tools.list_ports.comports()) #Gets info about devices connected

    for port in portList: #for each devices connected
        if port.pid == pidNano:
            comport = port.device

    return(comport)

startTrayIcon()

serialport = serial.Serial(findArduinoNanoPort(pidNano))


while not shouldIQuit:
    try:
        arduinostring = serialport.readline(128)
            #print(arduinostring)
    except:
        # Wait and restart serialport and go on
        time.sleep(10)
        serialport = serial.Serial(findArduinoNanoPort(pidNano))
        continue

    try:
        arduinoStringParts = arduinostring.decode('utf-8').split()
        channel = arduinoStringParts[0]
        value = 1-float(arduinoStringParts[1])
    except:
        # Corrupt command, drop it and move on
        continue

    if channel == "0": #Pause/play, next and previous track
        if value == 0:
            prevTrack()
        elif value == 1:
            pauseTrack()
        elif value == 2:
            nextTrack()
    elif channel == "4": #Systemsound
        pycawcalls.setSystemVolume(value)
    elif channel == "3": #Spotift Vlc
        pycawcalls.setAppVolumeName('Spotify.exe', value)
        pycawcalls.setAppVolumeName('vlc.exe', value)
        #nircmdcalls.levelfunk2(value)
    elif channel == "2": #Discord/Skype
        pycawcalls.setAppVolumeName('Discord.exe', value) #discord pid 4944 misc audio 11248 voice audio
        pycawcalls.setAppVolumeName('skype.exe', value)
    elif channel == "1": #Focused on
        window = win32gui.GetForegroundWindow() #Gets a handle on the foregroundwindow
        pids = win32process.GetWindowThreadProcessId(window) #uses the handle to get pid
        for pid in pids: #some programs have more then one pid
            pycawcalls.setAppVolumePid(pid, value)

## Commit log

2020-03-21 More things I forgot
    Arduino code
2020-03-26 Fix for media controls
    [Volymmixer.py]
2023-03-03 Added all the 3dcad files
    [Adapter.SLDPRT, Adapter.STL, Arduino Nano.SLDPRT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]
2023-03-27 Updated the software to work with the new RP2040 boards
2023-05-31 Added models to be printed
    [Pot adapter.3MF, Pot adapter.SLDPRT, Standof 4mm 9mm5.3MF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]
2023-05-31 Updated the 3dmodels after test print
    [Pot adapter.3MF, Pot adapter.SLDPRT, Standoff long.3MF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]
2023-06-02 modified the diameterer
    [Pot adapter.3MF, Pot adapter.SLDPRT]
2023-06-02 Strain Releif
    [Strain relief.3MF]
2023-06-02 Changed outer dimension
    [Pot adapter.3MF, Pot adapter.SLDPRT]
